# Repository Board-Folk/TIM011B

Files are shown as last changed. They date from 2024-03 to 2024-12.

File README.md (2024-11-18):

# TIM-011B

An updated remake of the TIM-011 computer from Serbia.

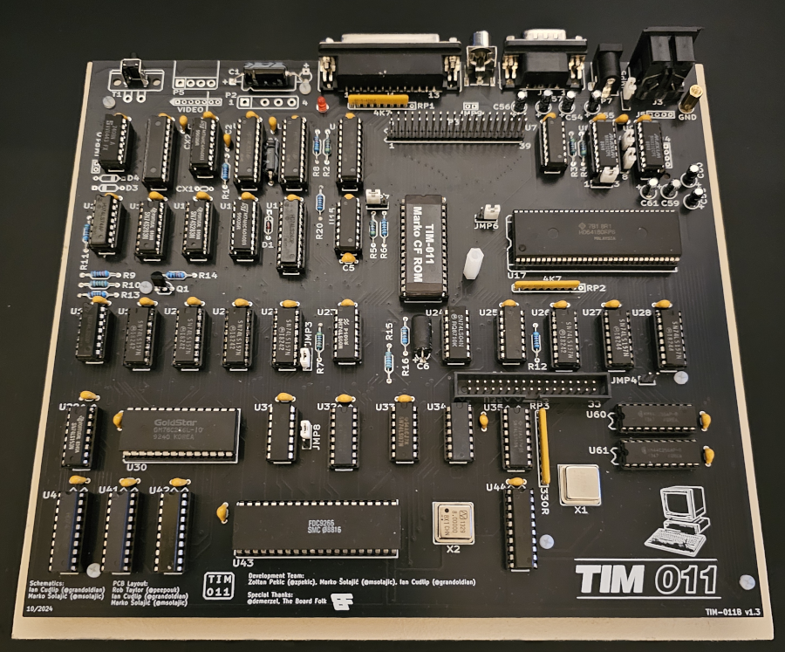
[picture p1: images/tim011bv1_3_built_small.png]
Image of build version 1.3 board in black


This repository contains the Bill-of-Materials (BOM), Gerbers and Kicad files for a remake of the TIM-011 from the Mihajlo Pupin Institute of Serbia, 1987.

The TIM-011 is a CP/M based computer that uses the Z80 family Hitachi HD64180 processor with 256KB RAM, 4 scale monochrome video and a FDC9266 floppy disk controller on the main board. It has an expansion bus, serial and parallel port and an ASCII keyboard interface. The system is built entirely from off-the-shelf parts that were commonly available at the time without any custom ULA or gate array chips. Most parts remain relatively easy to get hold of today online.

Version 1.1 does not deviate from the original board too much so it can still be considered a replica.

Version 1.2 includes 5V only operation, but due to stability issues this has not been published.

Version 1.3 contains improvements including composite video output, updated oscillators and stability fixes and uses a GAL for video sync signals. The initial version of this GAL is incompatible with the original screen, a modified version may be added in the future. From version 1.3, the board changed from using HC-49 crystals to TTL output DIP8 layout "square" can type oscillators.

Feel free to fork and make your own mods outside of this repository. Folder Extensions contains add on expansions and adapters for the board. More will follow over time.

The work-in-progress version of the board has been removed from this project. If you're looking to make one, pick the latest version from the Releases folder.

Projects are in Kicad 8.

## Building the board

A BOM is present in each release folder. The Kicad iBOM plugin has also been used to create an interactive BOM in the BOM subfolders for the main boards and expansion boards. Since these builds use obsolete parts, such as the CPU, FDC and RAM, we cannot provide any links to those parts. They are available on AliExpress and eBay, but many sellers will ship relabeled or faulty ICs. Be careful.

## Using the board

### Power

Version 1.1, as the original board requires 5V, 12V and -12V power. Power connectors on the board are the original Ei Niš connector P2, but due to the lack of availability of this part we've added P5, a standard 4 pin 3.96mm pin header to the rear of the board. 

Version 1.3 has a centre positive DC barrel jack for only 5V operation also.

### Video

Original video output is not standard, conversion is needed for use on a modern display. This works directly with the original screen and is the only output option on boards until version v1.3. The video fix extension board gives conversion to composite video for boards up to release v1.1. As a technical note, the original video output is provided as 2 TTL signals to giving 4 shades, with a relatively wide horizonal and vertical sync for the original CRT. The horizontal sync is in an awkward position and is more simlar to horizonal drive found on comparible systems with a simple in-build CRT display.

Version 1.3 adds a composite video output for use on standard monitors.

### Keyboard

The keyboard is serial ASCII, 9600 8E1 with a 12V power output on the 5 pin DIN header. Version 1.3 adds the option to switch this to 5V operation. Adapter boards are being added to the extensions folder for this and will also including modules for the v1.3 mainboard to contain keyboard conversion within the board footprint.

No operating system is included within the ROM - it needs to boot this from floppy disk or equivalent Gotek or Flash Floppy device. Marko's updated ROM for v1.3, which is backwards compatable adds diagnotics and support to boot from CF cards with the 8 bit CF/IDE expansion board and adapter.

More information to follow.

## TIM011 Resources

Marko Šolajić has put a great page together with a ROM, boot disks, software and other resources to help get the TIM-011 going. Highly recommended. The standard "sys", system ROM is 8KB, this will fit on the currently still manufactured and widely available AT28C64B.

  [TIM011 Resources](https://blog.8bitchip.info/tim011-resources/)
  
Marko is also documenting system software and has provided a new boot ROM. These can be found here:

  [TIM011 System Software](https://github.com/msolajic/tim011-system-software)

## Revisions

* Version 1.1 Initial Public Release
* Version 1.2 Unreleased
* Version 1.3 Current Release
  
### Version 1 Modifications from Original

* Fixed VSYNC Buffer
* Fix Strobe Pullup
* CX timing fix capacitor
* P5 3.96mm right angle power pin header 
* XT Keyboard INT0/SCROLL fix modification with JMP3 selection on/off
* Right angle reset momentatary switch within T1 footprint
* Modernise J3 keyboard connector footprint
* J4 and J5 serial pin headers for alternative serial connections
* Added mounting holes
* Power LED

### Version 1.1

* C42 silkscreen
* Fix J4 and J5 connections
* Silkscreen updates
* ROM A13 to GND
* Increase DB25 mounting point radius to 1.6mm
* Add JMP4 drive Ready/Disk Change modification

### Version 1.2

* 5V Only operation - added DC barrel jack
* Ceramic caps changed to 5.08mm
* Updated silkscreen
* JMP5 5V/12V keyboard selection
* A13,A14,A15 ROM options
* JMP8 No Video jumper
* Change serial to MAX232 (5V)
* RAM change to 44256
* "Half-can" Oscillators for X1 and X2
* JMP9 12V Power selection for expansion bus pin 40
* Grounding point
* Support for keyboard modules

### Version 1.3

* Replaced U2 74LS08 with GAL16V8
* Sync signals negative with standard GAL
* Change serial port to 9 pin
* Oscillators now buffered
* R8 reset pullup
* Composite video output

## Version 1.3 BOM

There are 3 options for board power, P2, P5 or P7. Ceramic capacitors 5.08mm and resistors 1/4W.

|Qty|Reference(s)|Value|Type|Notes|
|:--:|:--:|:--:|:--:|:--:|
|1|P1|5-7 pin header|Header|Video|
|1|P3|2x20 pin header|Dual Row 2.54mm Header|Expansion|
|1|P4|2x17 pin header|Dual Row 2.54mm Header|Floppy|
|1|P2|Unknown Ei Niš 4 pin header|Header|Power|
|1|P5|3.96mm 4 pin header|3.96mm Header|Alt Power|
|1|P7|DC Barrel Jack||5V Power|
|1|P8|RCA Jack||Composite Output|
|46|C3, C8, C10-C53|100nF|Ceramic Capacitor||
|1|C2|1nF|Ceramic Capacitor||
|1|C4|10uF 16V|Axial or Radial||
|1|C5|2n2|Ceramic Capacitor||
|1|C6|470uF 25V|Axial or Radial||
|8|C54-C57, C58-C61|1uF 16V|Radial||
|1|CX1, CX2|330pF|Ceramic Capacitor||
|1|D1|1N4148|Diode||
|1|D1|3mm LED|LED||
|2|R1, R12|470R|Resistor||
|1|R10|1K5|Resistor||
|1|R11|5K1|Resistor||
|2|R13, R20|1K|Resistor||
|1|R14|220R|Resistor||
|1|R15|10K|Resistor||
|1|R16|68R|Resistor||
|5|R2-R5, R7|4K7|Resistor||
|1|R6|100R|Resistor||
|1|R8|56K|Resistor||
|1|R9|2K2|Resistor||
|2|RP1, RP2|4K7 SIP10 Bussed|Resistor Network||
|1|RP3|330R SIP10 Bussed|Resistor Network||
|1|Q1|BC557|Transistor||
|1|U17|HD64180|IC|CPU|
|1|U43|FDC9266|IC|Floppy Controller|
|2|U8, U9|MAX232|IC|Serial Line Driver/Receiver|
|1|U16|27xxx ROM|IC|System ROM|
|2|U60, U61|44256 DRAM|IC|System RAM|
|1|U30|43256 SRAM|IC|Video RAM|
|1|U2|GAL16V8|IC|Sync Logic|
|1|U1|74LS08|IC||
|2|U11, U12|74LS283|IC||
|2|U14, U44|74LS240|IC||
|1|U18|74LS20|IC||
|7|U19-U22, U26-U28|74LS157|IC||
|1|U23|74LS00|IC||
|1|U24|74LS04|IC||
|1|U29|74HC153|IC||
|2|U3, U13|74HC4040|IC||
|1|U31|74LS32|IC||
|1|U32|74LS139|IC||
|1|U33|74LS07|IC||
|1|U34|74LS06|IC||
|1|U35|74LS158|IC||
|5|U4-U6, U40, U41|74LS374|IC||
|1|U42|74LS244|IC||
|4|U7, U10, U15, U25|74LS74|IC||
|1|T1|Unknown Reset Switch|Switch|T1 or T2|
|1|T2|RA Momentary Switch|Switch||
|1|J1|DB25 Female Right Angle|Socket|Printer|
|1|J3|5 pin DIN|Socket|180 degree / ASCII Keyboard|
|2|J4, J5|4 pin header|2.54mm Header|Alt TTL Serial|
|1|J6|DB9 Male Right Angle|Socket|Serial|
|1|JMP1, JMP3, JMP5-8|3 pin header|2.54mm Header||
|1|JMP2|5 pin header|2.54mm Header||
|1|JMP4|2 pin header|2.54mm Header|Fix Ready/Disk Change|
|1|X1|12.288MHz TTL Osc Can (DIP8)|Oscillator||
|1|X2|8MHz TTL Osc Can (DIP8)|Oscillator||

## Jumper Settings

Version 1.3

|Jumper|Description|Default|
|:--:|:--:|:--:|
|JMP1|CTS0 Select|2-3|
|JMP2|CTS/DCD Select|4-5,7-8|
|JMP3|XT Keyboard Fix|1-2 D Normal, 2-3 U Fix|
|JMP4|FDC Ready|Optional|
|JMP5|Keyboard Power|1-2 D 12V, 2-3 U 5V|
|JMP6|ROM A14|1-2 L 5V, 2-3 R A14|
|JMP7|ROM A15|1-2 L 5V, 2-3 R A15|
|JMP8|Video Bypass|1-2 U Normal, 2-3 D Disable|
|JMP9|12V Expansion Pin 40|NF|
|JMP10|HSYNC connection for CSYNC|Preset ON|

## Links

   [Marko's Blog Post on the TIM 011](https://blog.8bitchip.info/482-tim-011-a-new-life-for-an-old-computer/)

## Credits

PCB Layout by Rob Taylor @peepouk, Ian Cudlip @grandoldian and Marko Šolajić @msolajic. Schematics recreated and modifications by Ian Cudlip and Marko Šolajić. Special thanks to @demerzel, your schematics have helped and saved time.

## Thanks

* Zoltan Pekic
* @demerzel
* The Board Folk Team

## Legal

As the product of this project is a replica of a proprietary product, the the author makes no claim of copyright to the schematics nor PCB layouts and releases these into the public domain, solely for the purposes of study and historical preservation.

You are free to produce PCBs based on this project's designs at your own risk and without limitation, for your own use or for sale and/or repair at a reasonable price. Attribution is appreciated. The authors are not obliged to provide support of any kind. 

Under no circumstances will the authors be held responsible or liable in any way for losses, damages or costs resulting from the use of the information and/or resources of this project. 

The resources are provided "as-is" without warranty of any kind, either expressed or implied, including, but not limited to, the implied warranties of merchantability and fitness for a particular purpose.

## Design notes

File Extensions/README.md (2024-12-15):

# TIM-011B Extensions

Extension Boards for the TIM-011B

## TIMPS2Key

ATMega/Arduino based PS/2 Keyboard Adapter.

## TIMAYSound

AY-3-8910/12 expansion board for joystick and sound.

## tim011_video_fix

Video output board to create RGB and composite output from standard TIM-011 video signaling.

## TIMPS2KeyMini

Keyboard daughter card for mainboard v1.2 or later. For fitting a PS/2 keyboard interface within the mainboard footprint.

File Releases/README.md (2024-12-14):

# TIM-011B Releases

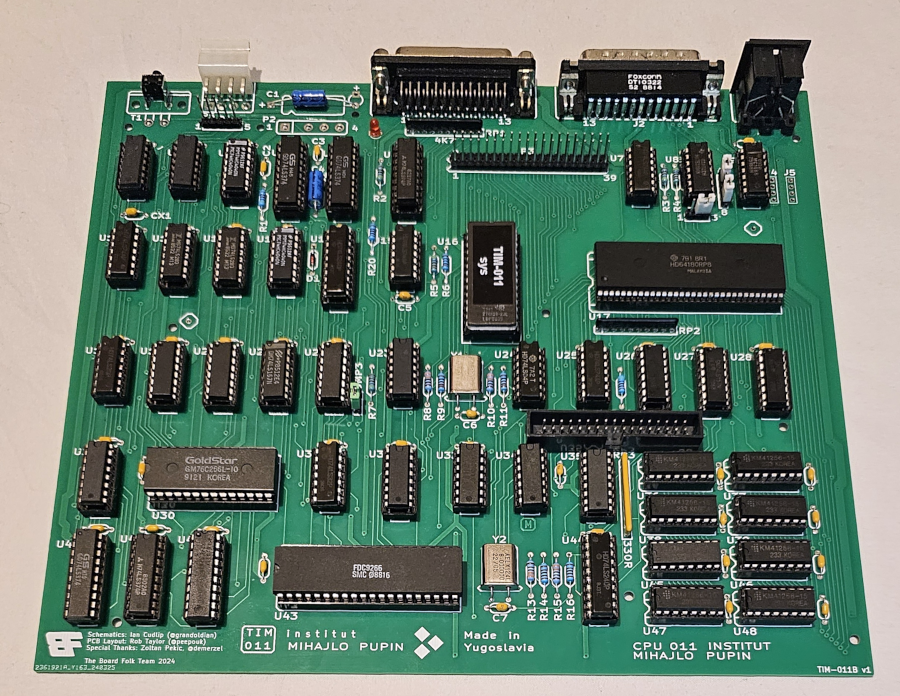
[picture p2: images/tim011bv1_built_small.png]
Image of build version 1 board in green


Each releases folder contains a Kicad, Gerbers and BOM folder, the latter containing the generated iBOM to help build the board.

Please check out the revision notes, currently on the repository home readme for changes and modifications.

## v1.1

12/04/2024

Initial public release. This doesn't deviate much from the original 1987 board.

## v1.3

16/11/2024

Contains improvements including composite video output, updated oscillators and stability fixes.

## v1.3.1

19/11/2024

Silkscreen fixes only.

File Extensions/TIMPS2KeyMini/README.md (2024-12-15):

# TIMPS2KeyMini

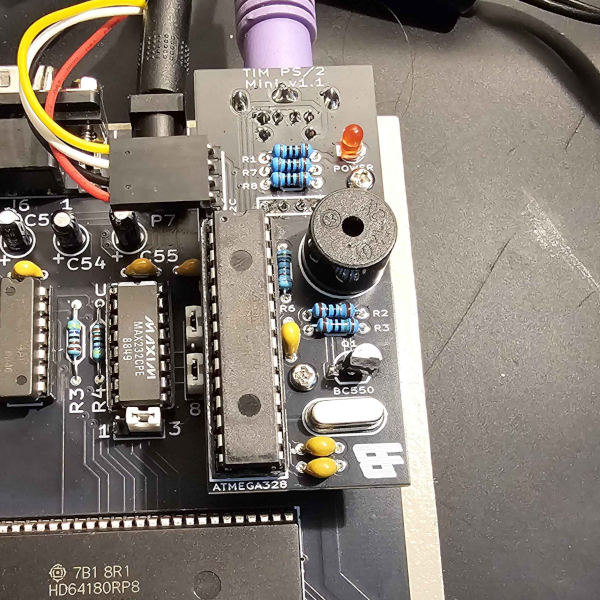
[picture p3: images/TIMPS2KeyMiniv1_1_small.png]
Image of build version 1.1 board in black


ATMega328 based PS/2 Keyboard Adapter. A daugherboard that will fit within the mainboard footprint instead of the traditional 5 pin DIN ASCII keyboard socket. This includes the i2c connector for the TIMI2CLEDPanel board which provides the LEDs.

## Versions

v1.1 Initial release

## Main board modifications

This fits instead of the external RS232 functionality of the original keyboard and connector (serial port RS232 remains). On the mainboard, do not fit the MAX232 at J9, the 5 pin DIN socket J3 and the charge caps C58-C61, fitting the 4 pin header J5 instead. Standoffs will needed to be mounted to secure the mini keyboard board and the pin length of the J5 header should match the standoff length. Recommendations may follow.

## Programming the ATMega328

The board doesn't include a programming header, the ATMega328 chip needs programming separately. The simplest way of doing this is with a Minipro with the appopriate fuse settings set in Xgpro. Tested settings are in the screenshot below and the exported binary and hex files for programming can be found in the export folder. For the arduino code see the main TIMPS2Key extension folder. 

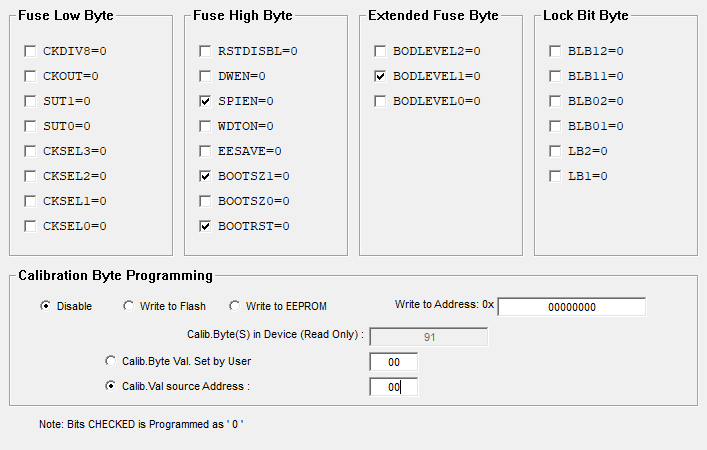
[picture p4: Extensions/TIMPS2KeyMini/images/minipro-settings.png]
Screenshot of minipro settings for the ATMega328 fuses


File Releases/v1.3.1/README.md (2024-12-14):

# TIM-011B v1.3.1

19/11/2024

Silkscreen update only, see v1.3

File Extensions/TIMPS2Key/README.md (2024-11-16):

# TIMPS2Key

ATMega/Arduino based PS/2 Keyboard Adapter. Will soon be adding the daughter board for v1.2 or later main boards which will allow fitting within the original board footprint instead of the related serial circuitry and DIN socket.

## Versions

v0 Prototype / Development board using Arduino Nano and a MAX232.

v1 Final Arduino Nano Version. Now includes sound and i2c output for LED panel.

v2 ATMEGA328 Version of v1

## Notes

For use on v1.2 or later main boards with 5V power output selected, bypass voltage regulator at U3 connecting pins 1 and 3

## TIMI2CLEDPanel

This folder contains an I2C connected board to output the keyboard LED display. It's intended to fit within a 3.5" drive blanking front panel blanking plate.

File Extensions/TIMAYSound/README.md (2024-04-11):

# TIMAYSound

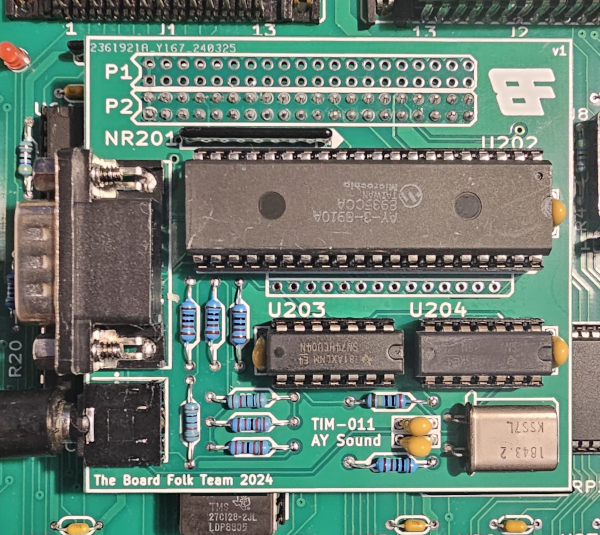
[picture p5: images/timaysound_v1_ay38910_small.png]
Image of build version 1 board in green


Sound card for the TIM-011 supporting the AY-3-8910 or AY-3-8912 sound generator chip. Featuring 3.5mm stereo line output and a DB-9 pin joystick port.

Note: Fit resistor network NR201 if you have an 'A' type chip, e.g. AY-3-8910A.

## Versions

v1 Initial version

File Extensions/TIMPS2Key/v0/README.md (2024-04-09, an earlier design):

# TIMPS2Key v0

ATMega/Arduino based PS/2 Keyboard Adapter. Prototype / Development board using Arduino Nano and a MAX232.

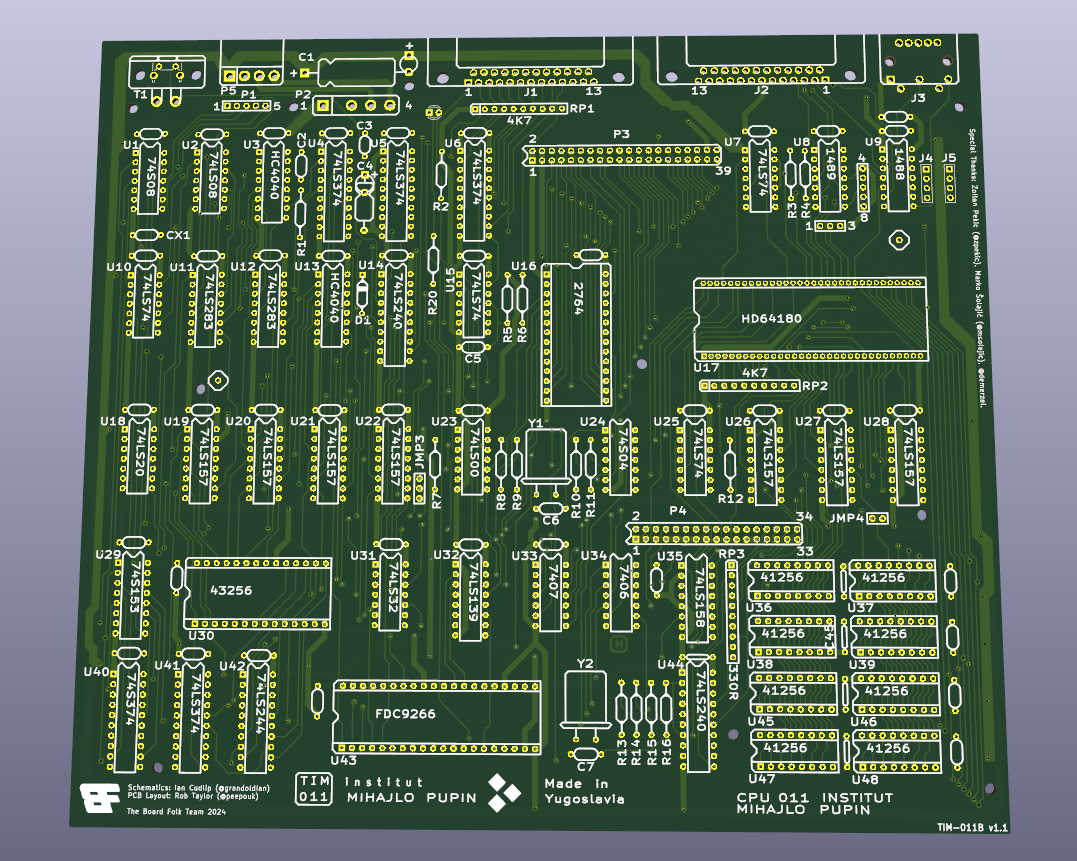
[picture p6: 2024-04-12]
images/TIM-011Bv1.1_render.png

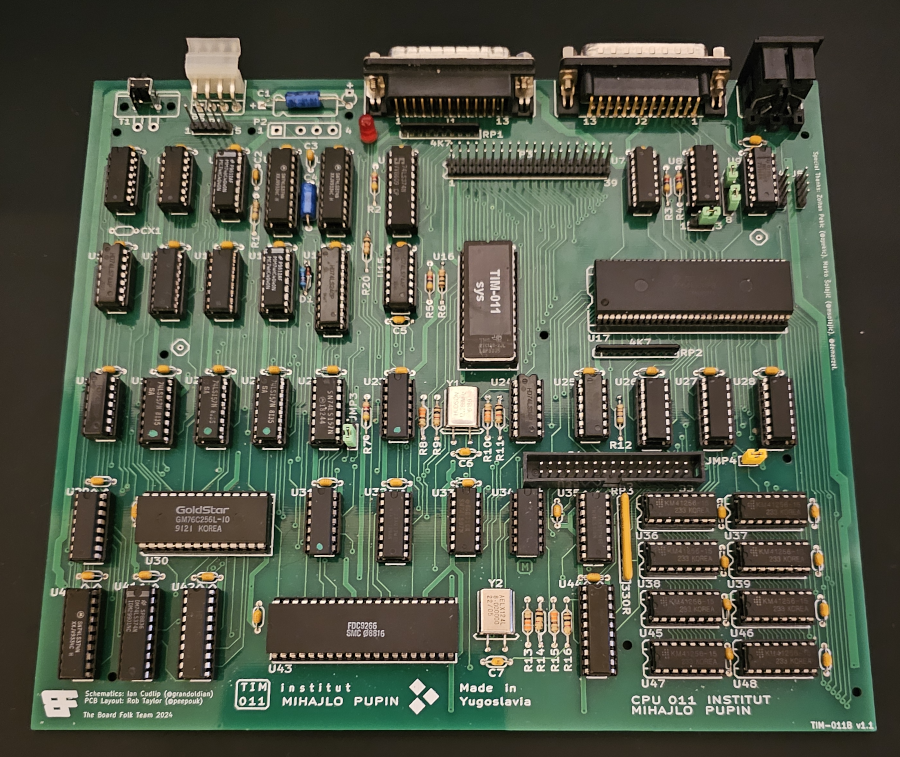
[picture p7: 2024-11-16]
images/tim011bv1_1_built_small.png

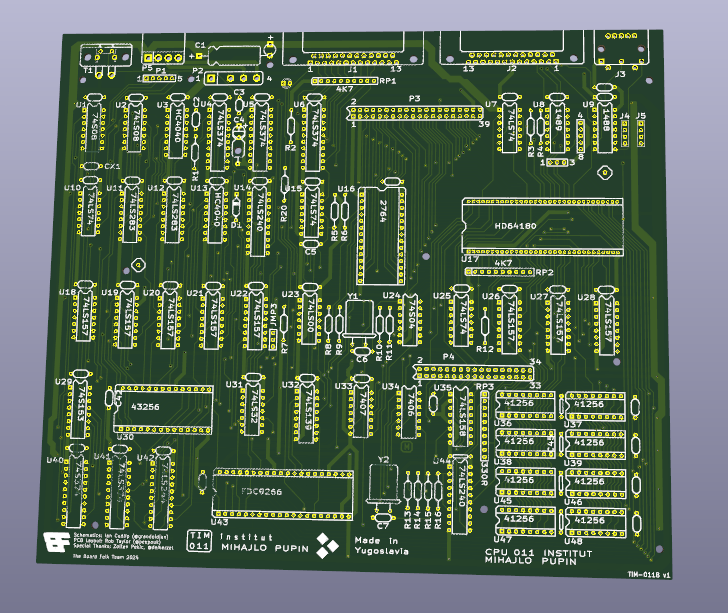
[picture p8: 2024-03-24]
images/TIM-011Bv1_render.png

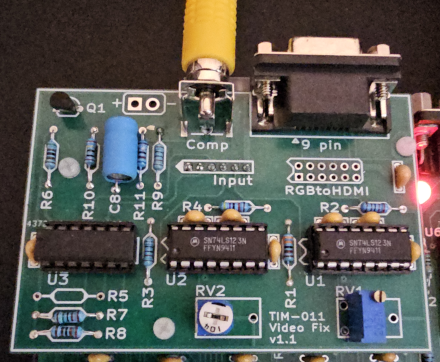
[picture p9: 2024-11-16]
images/timvideofixv1_1_small.png

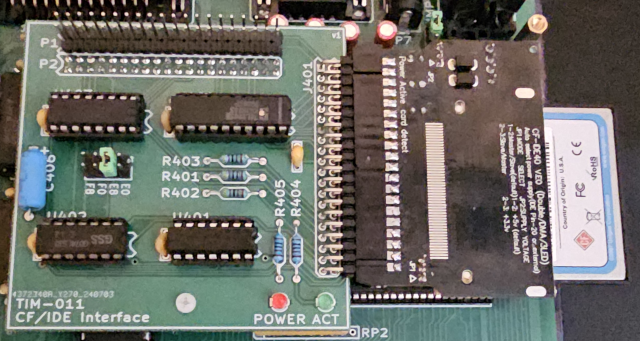
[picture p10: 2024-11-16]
images/timidev1_small.png

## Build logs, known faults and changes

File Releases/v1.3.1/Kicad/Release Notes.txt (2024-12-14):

v1 Initial Release

v1.1 

Remove C42 label
Fix J4, J5 connections
Fixed Zoltan credits silkscreen. Moved C6 and C7 down a little to avoid interference with crystals.
Fixed the 2 x silkscreen octagons so they are symmetrical.
Moved U15 designator to stop clash with R20 component and nearby via.
U18 label correction 74LS20
ROM A13 to GND
Increase DB25 mounting point radius to 1.6mm
Remove hole under C4
Credits change
Add JMP4 Floppy Ready/Disk Change Modification

v1.2

Change ceramic caps to 5.08mm
Remove IMP Branding, update credits
Change U24 label to 74LS04
JMP5 5V/12V Keyboard Voltage Selection
Connect A13 to ROM
A14,A15 ROM Jumpers JMP6, JMP7
JMP8 No Video jumper
Change 1488/1489 to MAX232
5V DC Barrel Jack
Change serial port to 9 pin
Move J5 to position as keyboard expansion
Replace RAM with 44256
"Half-can" Oscillators X1 and X2
12V Power to expansion pin 40 with JMP9
VSYNC selection jumper JMP10
TIM-011 Logo and Graphic
Grounding point

v1.3 (Attempt 1 - removed/reverted - ignore)

Remove U2 74LS08, add U2 74LS20
Move around signals to different inverter gates, free up inverters on U14 - move to U24
Update logic for generating sync signals, center image on screen with correct sync pulse length
Use (now free) inverters on U14 for creating logic for sync
Sync signals are now negative!
Rotated oscillators so they are oriented the same way with pin 1 bottom left
JMP10 is now obsolete, revert as per v1.1
Gave up on this
Reverted

v1.3

Remove U2 74LS08, add U2 GAL16V8
GAL16V8 will generate HSYNC, VSYNC, HRESET and VRESET
Sync signals are now negative!
JMP10 is now obsolete, revert as per v1.1
Serial port now changed to DE9 to make room for RCA/Composite jack
X1 moved
X1 and X2 now buffered with U44
Add R8 pull up for Reset
Added composite schematic from videofix board with adjustments and csync with diodes
JMP10 now preconfigued connection to HSYNC severable as VSYNC backfeeds back to the buffer output and original header
R13 considered optional in case of no sync on composite (remove if necessary)

v1.3.1

Update ROM Footprint

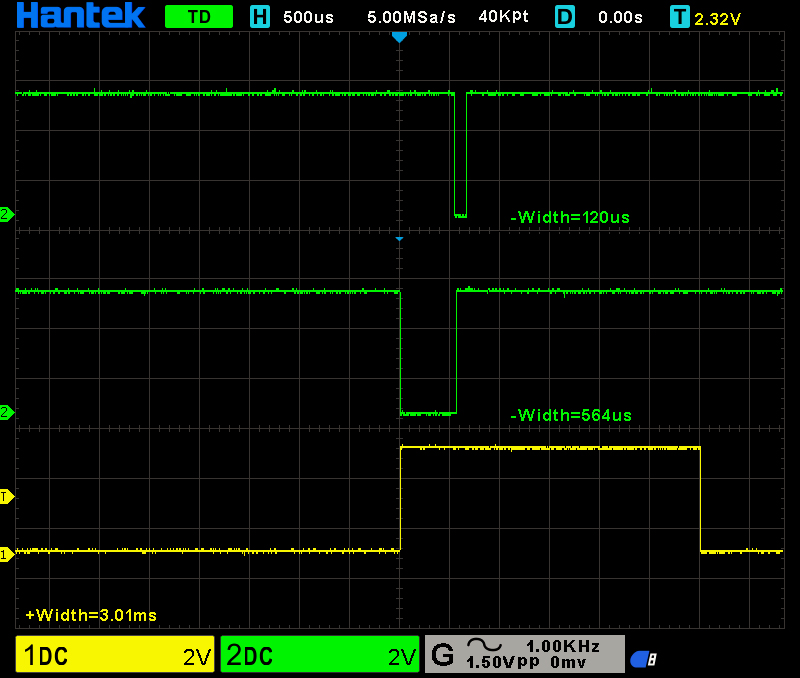
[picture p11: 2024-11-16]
Extensions/tim011_video_fix/images/vsync.jpg

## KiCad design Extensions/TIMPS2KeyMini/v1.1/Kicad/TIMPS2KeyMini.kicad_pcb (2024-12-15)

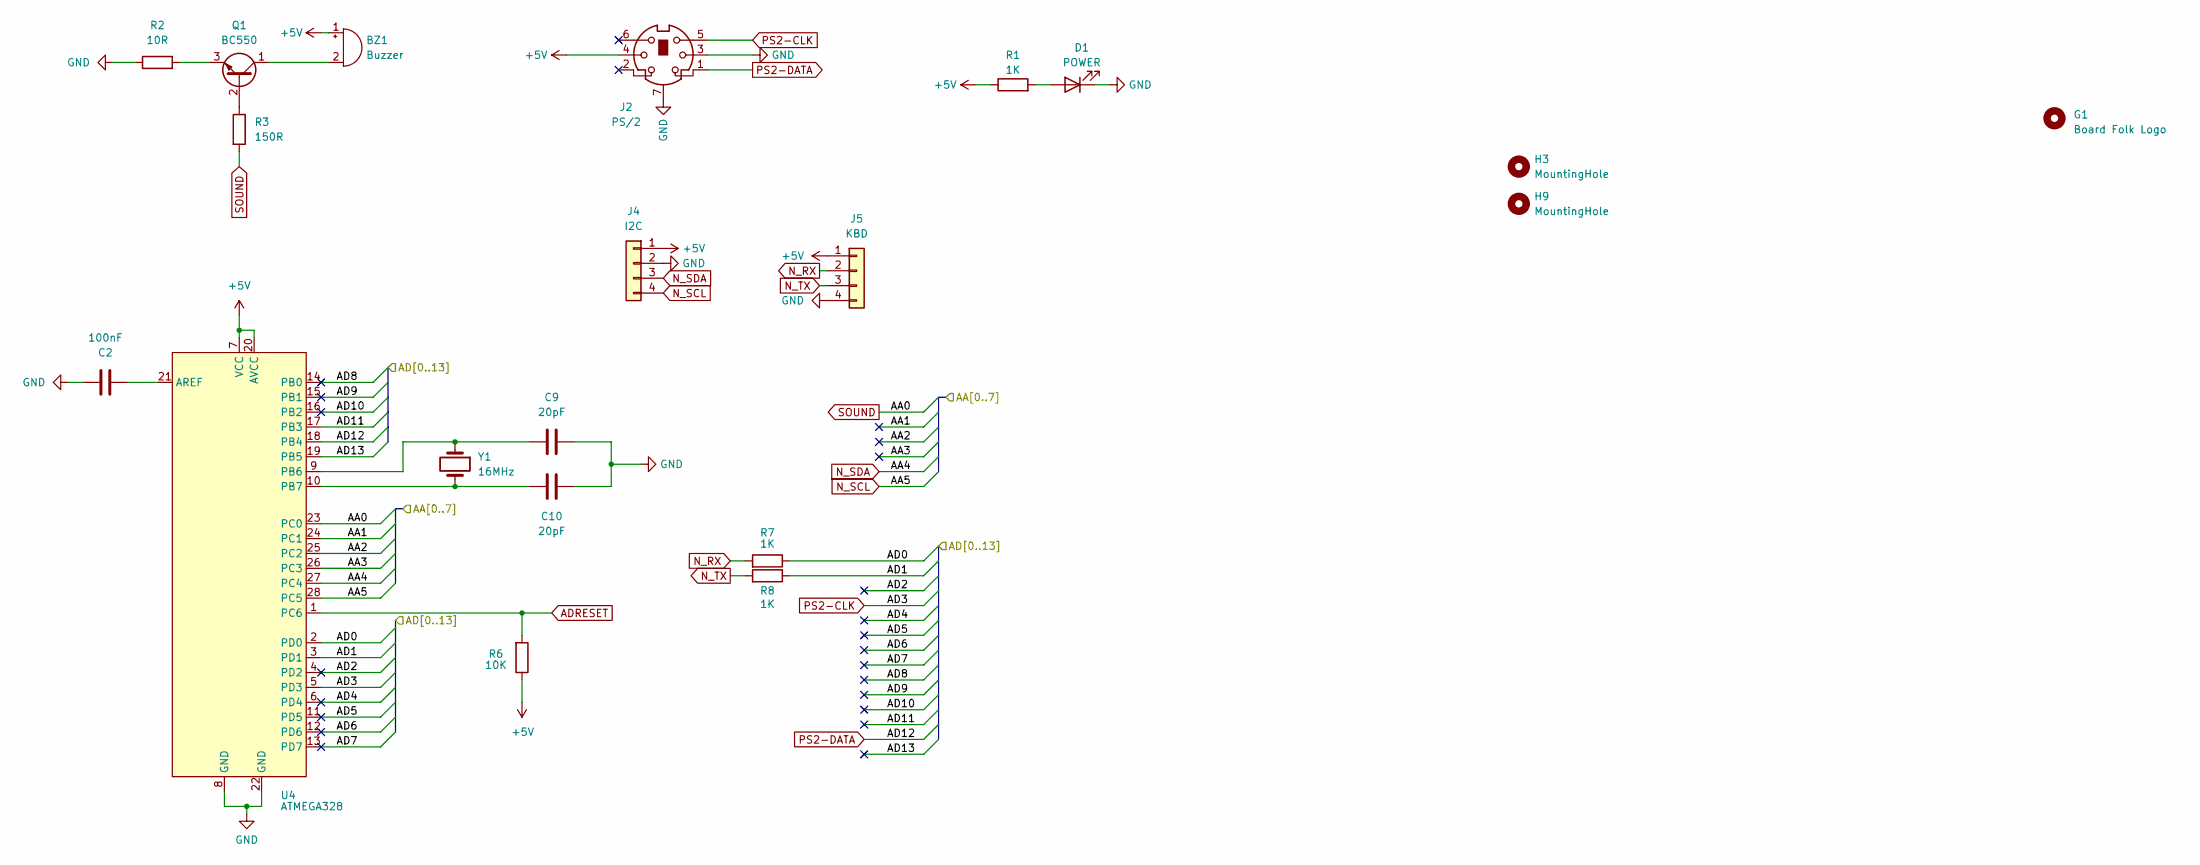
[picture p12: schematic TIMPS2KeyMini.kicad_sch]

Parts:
BZ1: Buzzer
C2: 100nF; Ceramic Cap 5.08mm
C9, C10: 20pF; Ceramic Cap 5.08mm
D1: POWER; LED_D3.0mm
G1: Board Folk Logo; BF8
H3, H9: MountingHole; MountingHole_M2.5
J2: PS/2; Connector_Mini-DIN_Female_6Pin_2rows
J4: I2C; PinHeader_1x04_2.54mm
J5: KBD; PinHeader_1x04_2.54mm
Q1: BC550; TO-92_Inline_Wide
R1, R7, R8: 1K; Resistor 7.62mm
R2: 10R; Resistor 7.62mm
R3: 150R; Resistor 7.62mm
R6: 10K; Resistor 7.62mm
U4: ATMEGA328; DIP-28_W7.62mm_Socket
Y1: 16MHz; Crystal_HC49-U_Vertical

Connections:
+5V: BZ1.1 (+), J2.4, J4.1, J5.1, R1.1, R6.1, U4.7 (VCC), U4.20 (AVCC)
/AA1: U4.24 (PC1)
/AA2: U4.25 (PC2)
/AA3: U4.26 (PC3)
/AD0: R7.1, U4.2 (PD0)
/AD1: R8.1, U4.3 (PD1)
/AD2: U4.4 (PD2)
/AD4: U4.6 (PD4)
/AD5: U4.11 (PD5)
/AD6: U4.12 (PD6)
/AD7: U4.13 (PD7)
/AD8: U4.14 (PB0)
/AD9: U4.15 (PB1)
/AD10: U4.16 (PB2)
/AD11: U4.17 (PB3)
/AD13: U4.19 (PB5)
ADRESET: R6.2, U4.1 (PC6)
GND: C2.2, C9.2, C10.2, D1.1 (K), J2.3, J2.7, J4.2, J5.4, R2.1, U4.8 (GND), U4.22 (GND)
N_RX: J5.2, R7.2
N_SCL: J4.4, U4.28 (PC5)
N_SDA: J4.3, U4.27 (PC4)
N_TX: J5.3, R8.2
unnamed: BZ1.2 (-), Q1.1 (C)
unnamed: D1.2 (A), R1.2
unnamed: Q1.2 (B), R3.1
unnamed: Q1.3 (E), R2.2
unnamed: C2.1, U4.21 (AREF)
unnamed: C9.1, U4.9 (PB6), Y1.1
unnamed: C10.1, U4.10 (PB7), Y1.2
PS2-CLK: J2.5, U4.5 (PD3)
PS2-DATA: J2.1, U4.18 (PB4)
SOUND: R3.2, U4.23 (PC0)

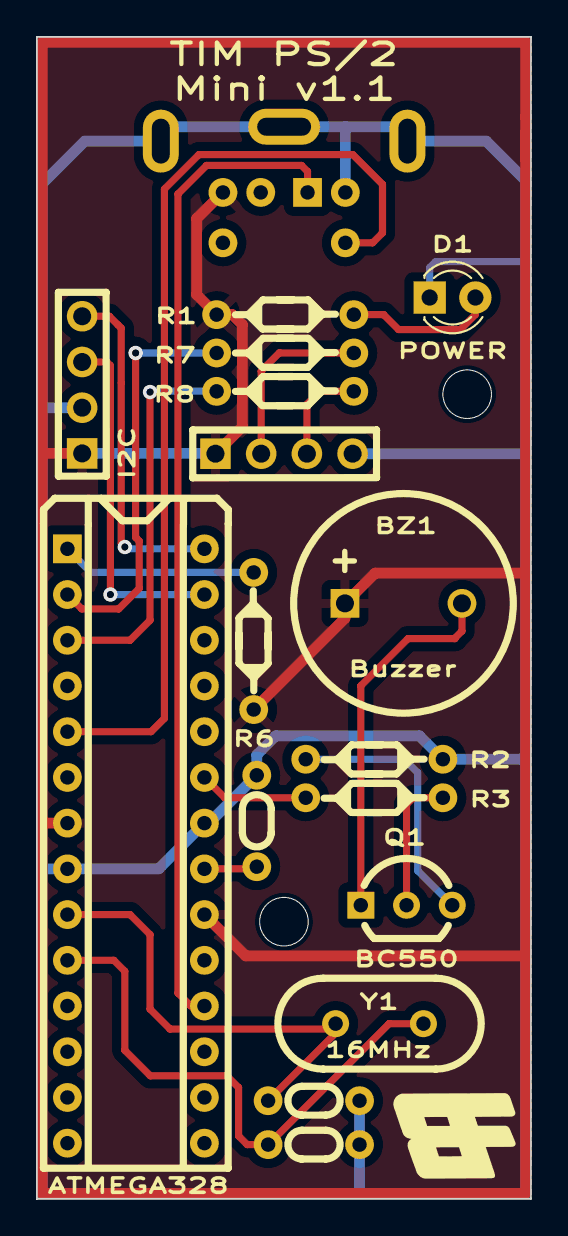
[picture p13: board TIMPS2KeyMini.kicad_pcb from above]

Board: 2 copper layers, 27.5 x 64.6 mm, 20 parts (1 on the bottom side), 19 nets.

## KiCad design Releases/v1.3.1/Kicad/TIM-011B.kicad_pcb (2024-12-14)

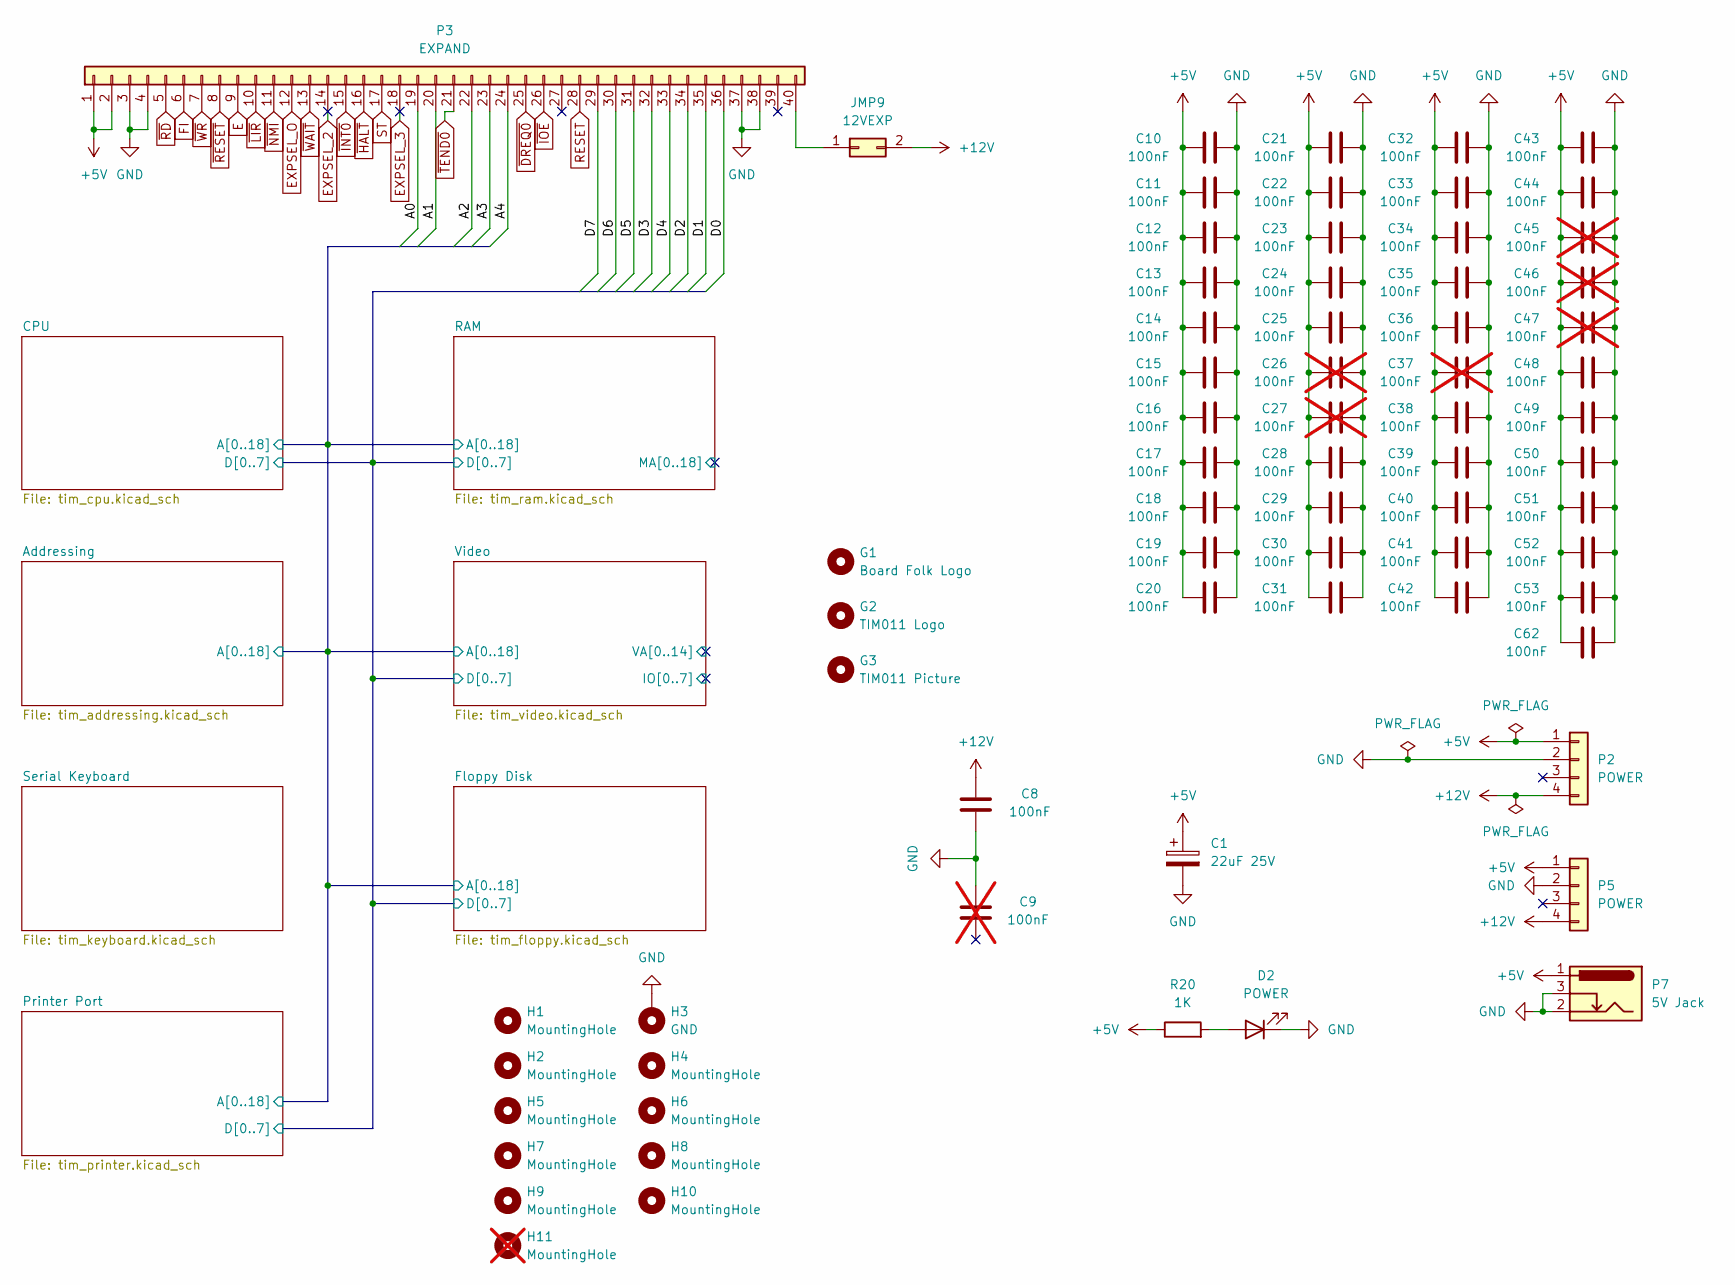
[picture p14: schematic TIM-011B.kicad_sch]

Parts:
C1: 22uF 25V; Electrolytic Capacitor Axial or Radial
C8, C10, C11, C12, C13, C14, C15, C16, C17, C18, C19, C20, C21, C22, C23, C24, C25, C28, C29, C30, C31, C32, C33, C34, C35, C36, C38, C39, C40, C41, C42, C43, C44, C48, C49, C50, C51, C52, C53, C62: 100nF; Ceramic Cap 5.08mm
C9, C26, C27, C37, C45, C46, C47: 100nF; Ceramic Cap 5.08mm; not fitted
D2: POWER; LED_D3.0mm
G1: Board Folk Logo; BF8
G2: TIM011 Logo; tim011logo
G3: TIM011 Picture; tim011_picture
H1, H2, H4, H5, H6, H7, H8, H9, H10: MountingHole; MountingHole_M2.5
H3: GND; TIM_MountingHole_2.5mm_Pad
H11: MountingHole; MountingHole_M2.5; not fitted
JMP9: 12VEXP; PinHeader_1x02 2.54mm
P2: POWER; P2
P3: EXPAND; PinHeader_2x20 2.54mm
P5: POWER; 3.96mm Header 4-Pin Edge
P7: 5V Jack; TIM_BarrelJack_Horizontal
R20: 1K; Resistor 12.7mm

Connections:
+5V: C1.1, C10.1, C11.1, C12.1, C13.1, C14.1, C15.1, C16.1, C17.1, C18.1, C19.1, C20.1, C21.1, C22.1, C23.1, C24.1, C25.1, C26.1, C27.1, C28.1, C29.1, C30.1, C31.1, C32.1, C33.1, C34.1, C35.1, C36.1, C37.1, C38.1, C39.1, C40.1, C41.1, C42.1, C43.1, C44.1, C45.1, C46.1, C47.1, C48.1, C49.1, C50.1, C51.1, C52.1, C53.1, C62.1, P2.1, P3.1, P3.2, P5.1, P7.1, R20.1; also elsewhere on the board
+12V: C8.1, JMP9.2, P2.4, P5.4; also elsewhere on the board
/Addressing/A0: P3.19; also elsewhere on the board
/Addressing/A1: P3.20; also elsewhere on the board
/Addressing/A2: P3.22; also elsewhere on the board
/Addressing/A3: P3.23; also elsewhere on the board
/Addressing/A4: P3.24; also elsewhere on the board
/CPU/D0: P3.36; also elsewhere on the board
/CPU/D1: P3.35; also elsewhere on the board
/CPU/D2: P3.34; also elsewhere on the board
/CPU/D3: P3.32; also elsewhere on the board
/CPU/D4: P3.33; also elsewhere on the board
/CPU/D5: P3.31; also elsewhere on the board
/CPU/D6: P3.30; also elsewhere on the board
/CPU/D7: P3.29; also elsewhere on the board
E: P3.9; also elsewhere on the board
EXPSEL_2: P3.14
EXPSEL_3: P3.18
EXPSEL_O: P3.12; also elsewhere on the board
FI: P3.6; also elsewhere on the board
GND: C1.2, C8.2, C9.1, C10.2, C11.2, C12.2, C13.2, C14.2, C15.2, C16.2, C17.2, C18.2, C19.2, C20.2, C21.2, C22.2, C23.2, C24.2, C25.2, C26.2, C27.2, C28.2, C29.2, C30.2, C31.2, C32.2, C33.2, C34.2, C35.2, C36.2, C37.2, C38.2, C39.2, C40.2, C41.2, C42.2, C43.2, C44.2, C45.2, C46.2, C47.2, C48.2, C49.2, C50.2, C51.2, C52.2, C53.2, C62.2, D2.1 (K), H3.1, P2.2, P3.3, P3.4, P3.37, P3.38, P5.2, P7.2, P7.3; also elsewhere on the board
unnamed: D2.2 (A), R20.2
unnamed: JMP9.1, P3.40
RESET: P3.28; also elsewhere on the board
ST: P3.17; also elsewhere on the board
~DREQ0: P3.25; also elsewhere on the board
~HALT: P3.16; also elsewhere on the board
~INT0: P3.15; also elsewhere on the board
~IOE: P3.26; also elsewhere on the board
~LIR: P3.10; also elsewhere on the board
~NMI: P3.11; also elsewhere on the board
~RD: P3.5; also elsewhere on the board
~RESET: P3.8; also elsewhere on the board
~TEND0: P3.21; also elsewhere on the board
~WAIT: P3.13; also elsewhere on the board
~WR: P3.7; also elsewhere on the board

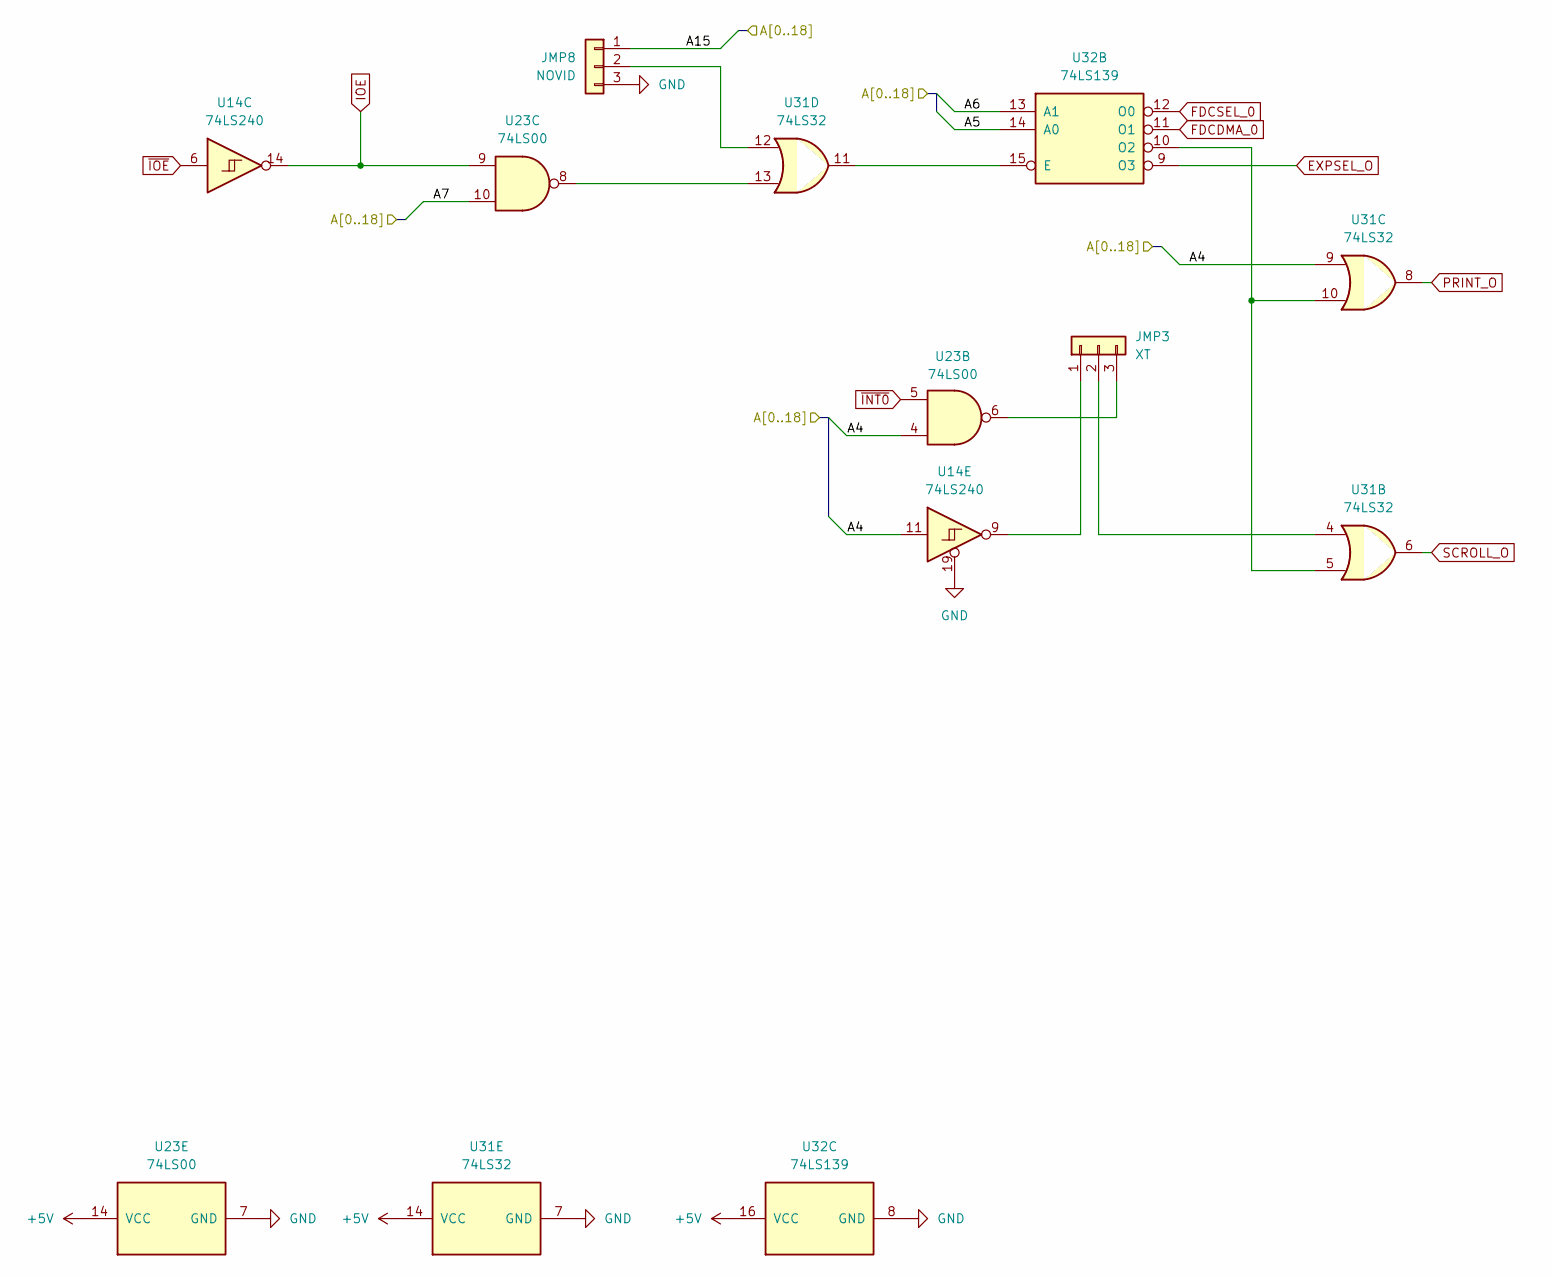
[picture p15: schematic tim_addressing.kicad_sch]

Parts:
JMP3: XT; PinHeader_1x03 2.54mm
JMP8: NOVID; PinHeader_1x03 2.54mm
U14: 74LS240; DIP-20_W7.62mm
U23: 74LS00; DIP-14_W7.62mm
U31: 74LS32; DIP-14_W7.62mm
U32: 74LS139; DIP-16_W7.62mm

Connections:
+5V: U23.14 (VCC), U31.14 (VCC), U32.16 (VCC); also elsewhere on the board
/Addressing/A4: U14.11, U23.4, U31.9; also elsewhere on the board
/Addressing/A5: U32.14 (A0); also elsewhere on the board
/Addressing/A6: U32.13 (A1); also elsewhere on the board
/Addressing/A7: U23.10; also elsewhere on the board
/Addressing/A15: JMP8.1; also elsewhere on the board
EXPSEL_O: U32.9 (O3); also elsewhere on the board
FDCDMA_0: U32.11 (O1); also elsewhere on the board
FDCSEL_0: U32.12 (O0); also elsewhere on the board
GND: JMP8.3, U14.19, U23.7 (GND), U31.7 (GND), U32.8 (GND); also elsewhere on the board
IOE: U14.14, U23.9; also elsewhere on the board
unnamed: JMP3.1, U14.9
unnamed: JMP3.2, U31.4
unnamed: JMP3.3, U23.6
unnamed: JMP8.2, U31.12
unnamed: U23.8, U31.13
unnamed: U31.11, U32.15 (E)
unnamed: U31.5, U31.10, U32.10 (O2)
PRINT_O: U31.8; also elsewhere on the board
SCROLL_O: U31.6; also elsewhere on the board
~INT0: U23.5; also elsewhere on the board
~IOE: U14.6; also elsewhere on the board

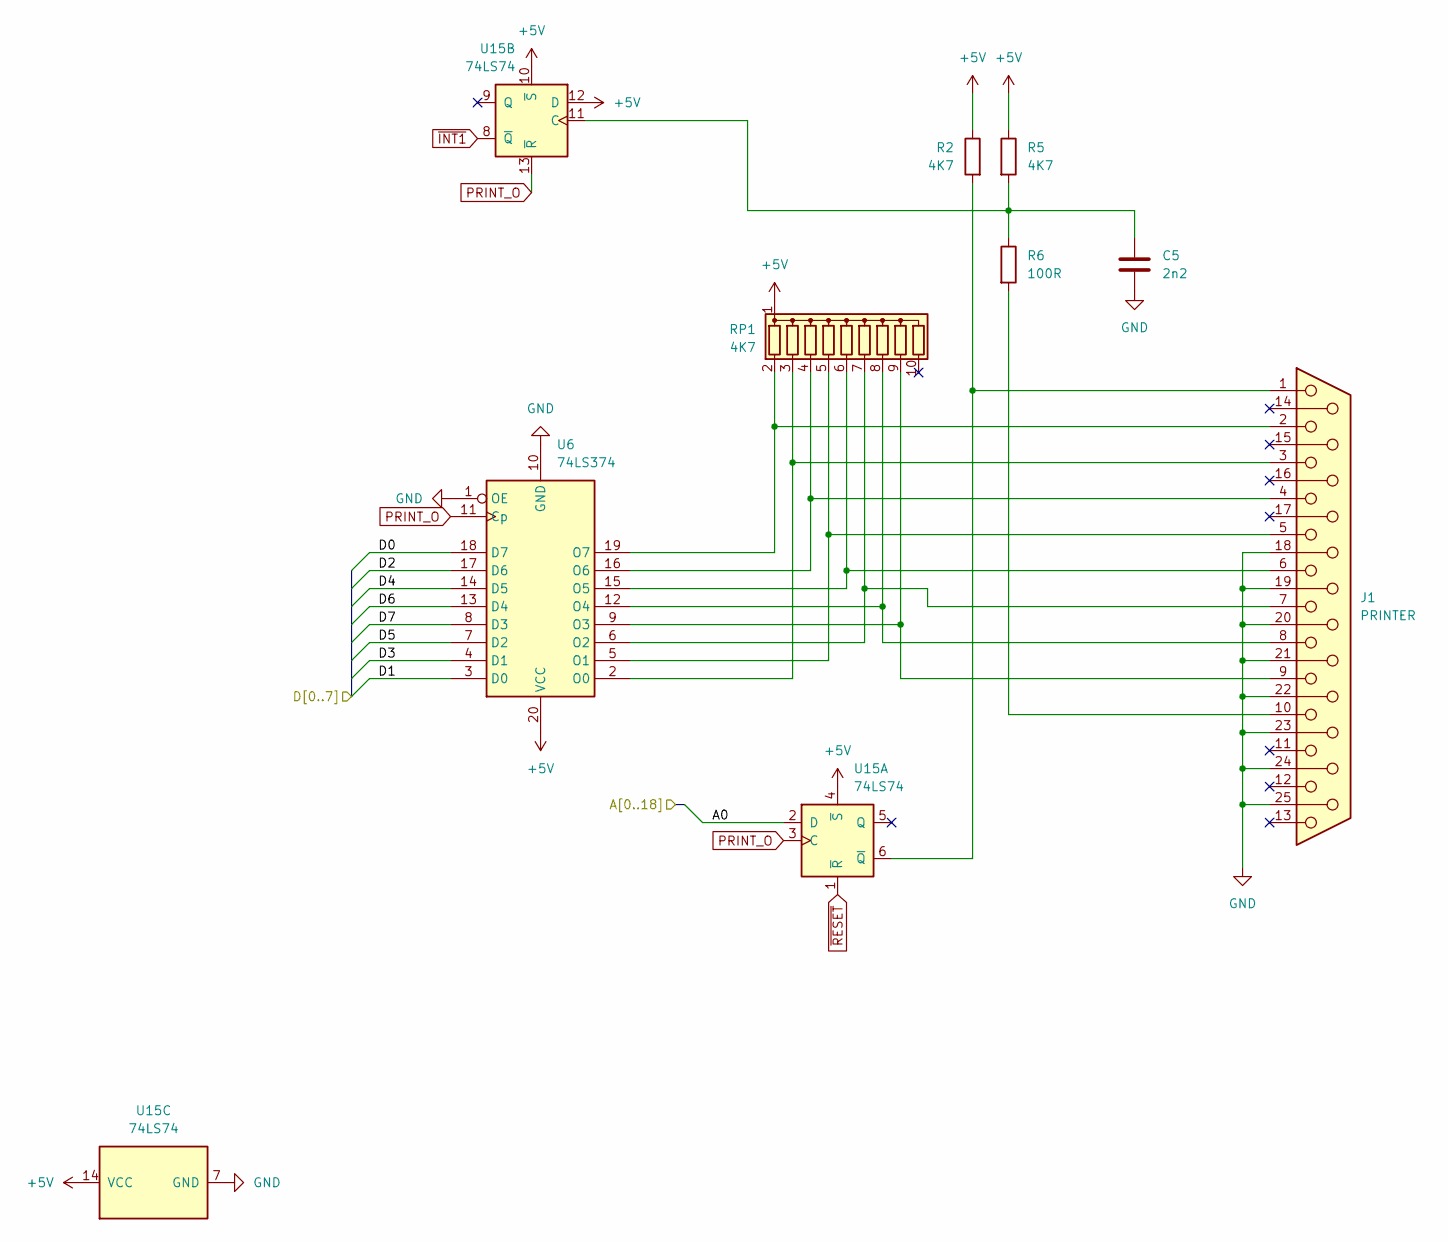
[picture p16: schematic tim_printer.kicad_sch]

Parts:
C5: 2n2; Ceramic Cap 5.08mm
J1: PRINTER
R2, R5: 4K7; Resistor 12.7mm
R6: 100R; Resistor 12.7mm
RP1: 4K7; R_Array_SIP10
U6: 74LS374; DIP-20_W7.62mm
U15: 74LS74; DIP-14_W7.62mm

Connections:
+5V: R2.1, R5.1, RP1.1 (common), U6.20 (VCC), U15.4 (~S), U15.10 (~S), U15.12 (D), U15.14 (VCC); also elsewhere on the board
/Addressing/A0: U15.2 (D); also elsewhere on the board
/CPU/D0: U6.18 (D7); also elsewhere on the board
/CPU/D1: U6.3 (D0); also elsewhere on the board
/CPU/D2: U6.17 (D6); also elsewhere on the board
/CPU/D3: U6.4 (D1); also elsewhere on the board
/CPU/D4: U6.14 (D5); also elsewhere on the board
/CPU/D5: U6.7 (D2); also elsewhere on the board
/CPU/D6: U6.13 (D4); also elsewhere on the board
/CPU/D7: U6.8 (D3); also elsewhere on the board
GND: C5.2, J1.18, J1.19, J1.20, J1.21, J1.22, J1.23, J1.24, J1.25, U6.1 (OE), U6.10 (GND), U15.7 (GND); also elsewhere on the board
unnamed: J1.10, R6.2
unnamed: J1.2, RP1.2 (R1), U6.19 (O7)
unnamed: J1.3, RP1.3 (R2), U6.2 (O0)
unnamed: J1.4, RP1.4 (R3), U6.16 (O6)
unnamed: J1.5, RP1.5 (R4), U6.5 (O1)
unnamed: J1.6, RP1.6 (R5), U6.15 (O5)
unnamed: J1.7, RP1.7 (R6), U6.6 (O2)
unnamed: J1.8, RP1.8 (R7), U6.12 (O4)
unnamed: J1.9, RP1.9 (R8), U6.9 (O3)
unnamed: J1.1, R2.2, U15.6 (~Q)
unnamed: C5.1, R5.2, R6.1, U15.11 (C)
PRINT_O: U6.11 (Cp), U15.3 (C), U15.13 (~R); also elsewhere on the board
~INT1: U15.8 (~Q); also elsewhere on the board
~RESET: U15.1 (~R); also elsewhere on the board

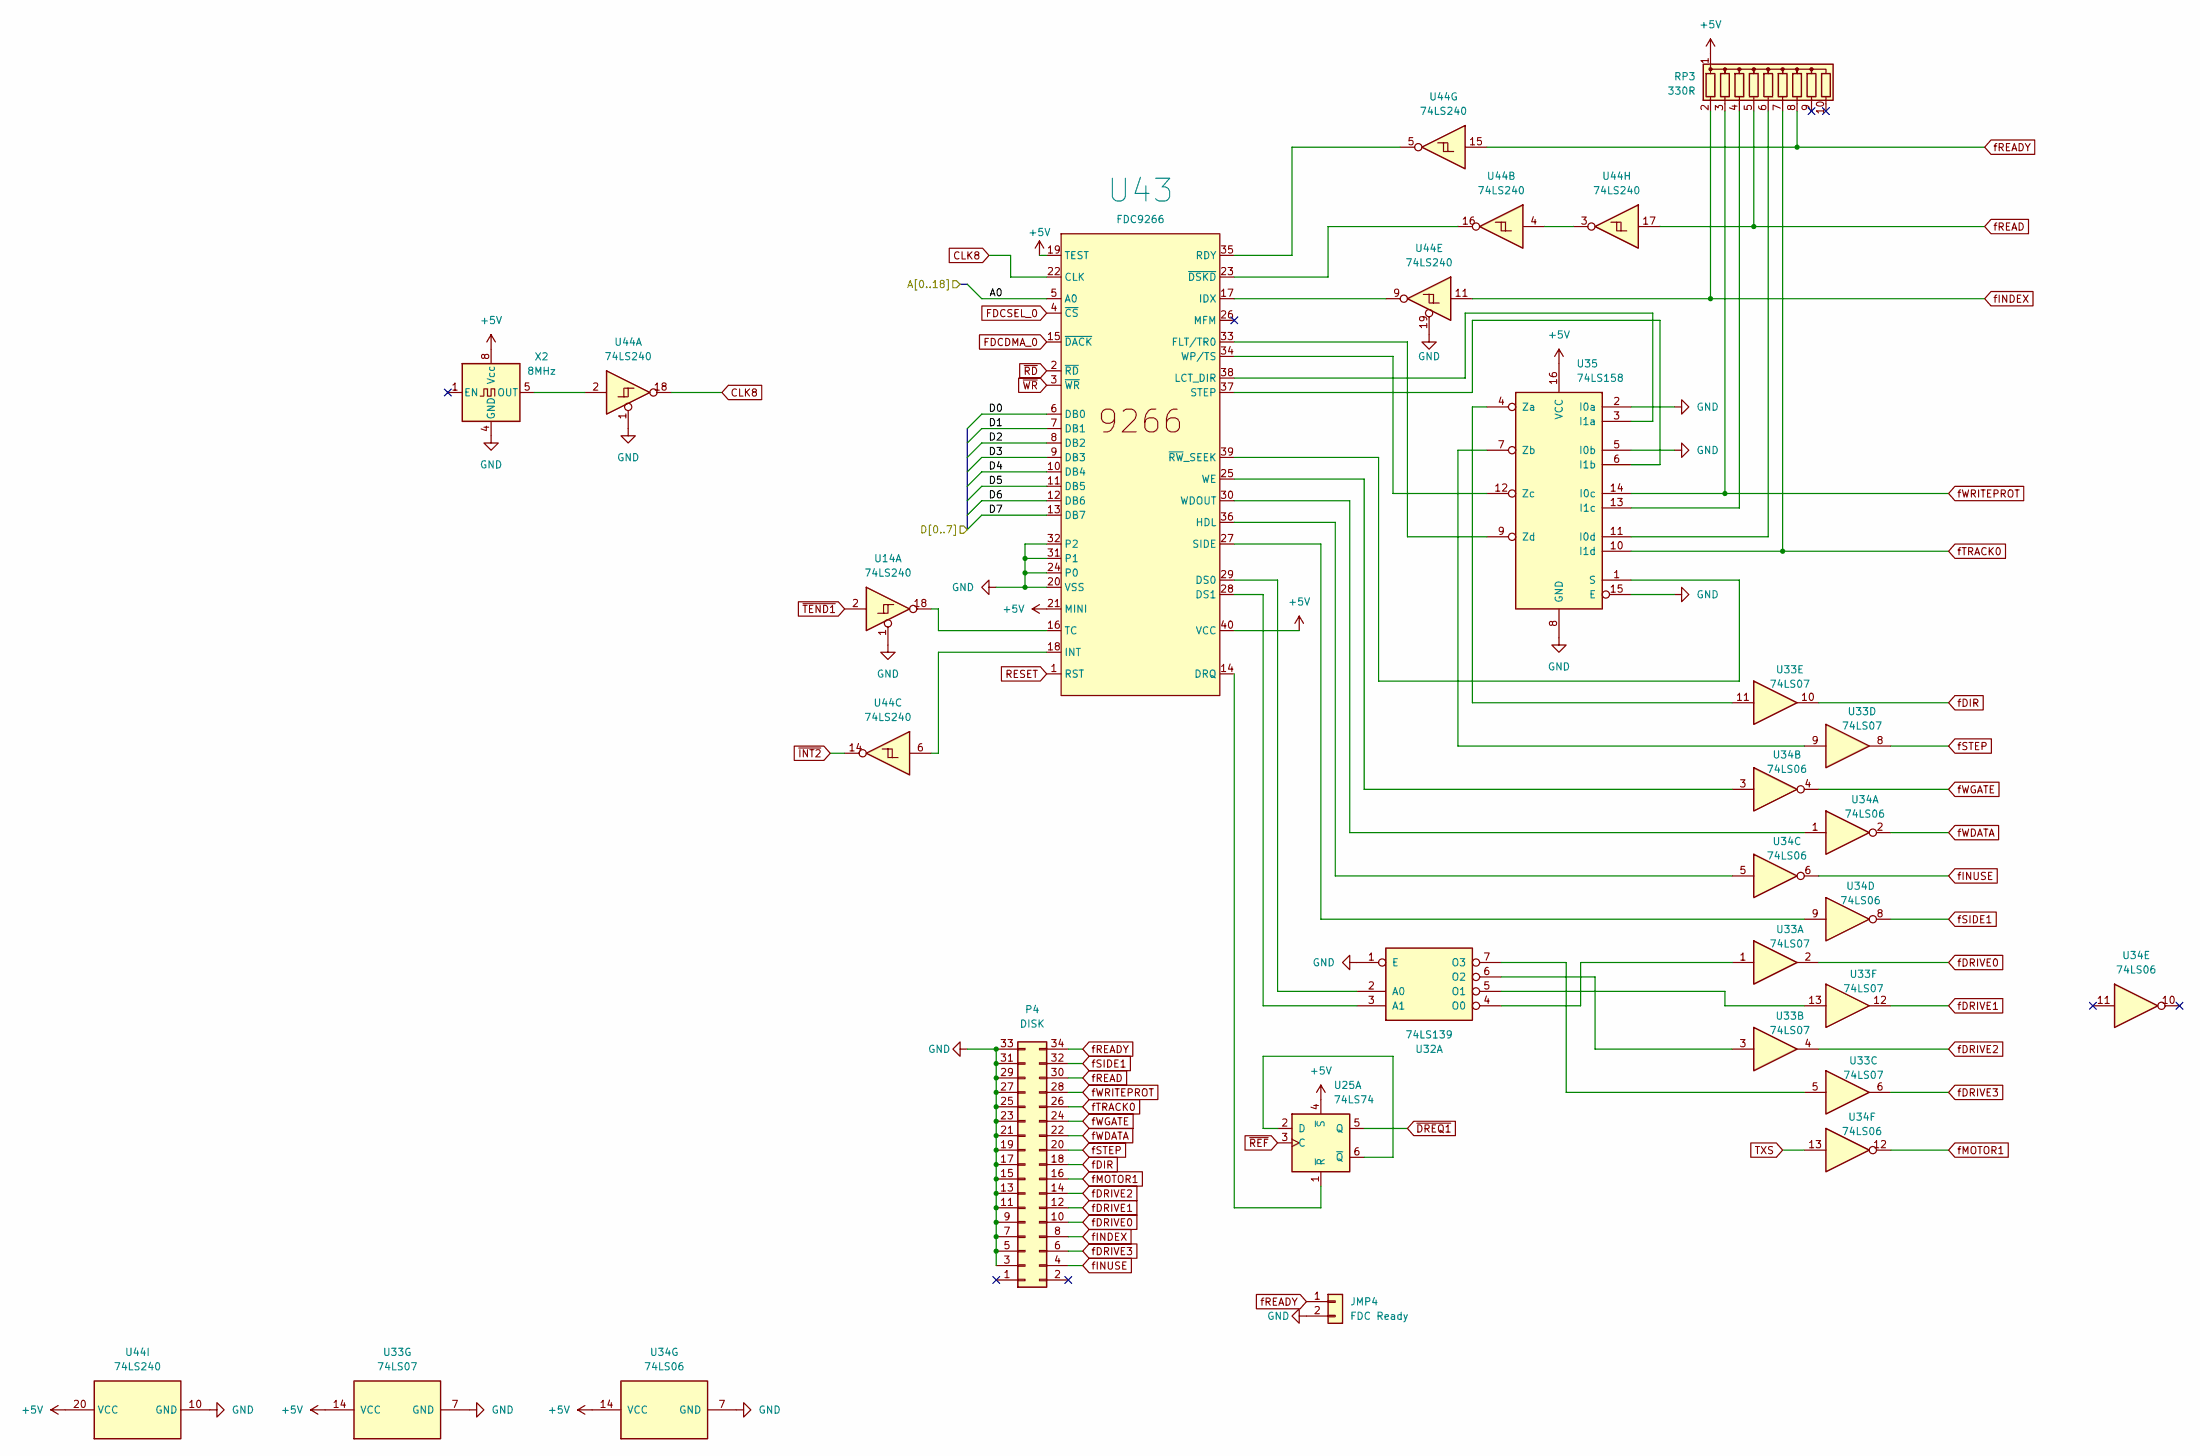
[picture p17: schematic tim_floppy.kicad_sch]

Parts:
JMP4: FDC Ready; PinHeader_1x02 2.54mm
P4: DISK; PinHeader_2x17_2.54mm
RP3: 330R; R_Array_SIP10
U14, U44: 74LS240; DIP-20_W7.62mm
U25: 74LS74; DIP-14_W7.62mm
U32: 74LS139; DIP-16_W7.62mm
U33: 74LS07; DIP-14_W7.62mm
U34: 74LS06; DIP-14_W7.62mm
U35: 74LS158; DIP-16_W7.62mm
U43: FDC9266; DIP-40_W15.24mm_Socket
X2: 8MHz; TIM_Oscillator_DIP-8

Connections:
+5V: RP3.1 (common), U25.4 (~S), U33.14 (VCC), U34.14 (VCC), U35.16 (VCC), U43.19 (TEST), U43.21 (MINI), U43.40 (VCC), U44.20 (VCC), X2.8 (Vcc); also elsewhere on the board
/Addressing/A0: U43.5 (A0); also elsewhere on the board
/CPU/D0: U43.6 (DB0); also elsewhere on the board
/CPU/D1: U43.7 (DB1); also elsewhere on the board
/CPU/D2: U43.8 (DB2); also elsewhere on the board
/CPU/D3: U43.9 (DB3); also elsewhere on the board
/CPU/D4: U43.10 (DB4); also elsewhere on the board
/CPU/D5: U43.11 (DB5); also elsewhere on the board
/CPU/D6: U43.12 (DB6); also elsewhere on the board
/CPU/D7: U43.13 (DB7); also elsewhere on the board
CLK8: U43.22 (CLK), U44.18
FDCDMA_0: U43.15 (~DACK); also elsewhere on the board
FDCSEL_0: U43.4 (~CS); also elsewhere on the board
GND: JMP4.2, P4.3, P4.5, P4.7, P4.9, P4.11, P4.13, P4.15, P4.17, P4.19, P4.21, P4.23, P4.25, P4.27, P4.29, P4.31, P4.33, U14.1, U32.1 (E), U33.7 (GND), U34.7 (GND), U35.2 (I0a), U35.5 (I0b), U35.8 (GND), U35.15 (E), U43.20 (VSS), U43.24 (P0), U43.31 (P1), U43.32 (P2), U44.1, U44.10 (GND), U44.19, X2.4 (GND); also elsewhere on the board
unnamed: RP3.4 (R3), U35.13 (I1c)
unnamed: RP3.6 (R5), U35.11 (I0d)
unnamed: U25.2 (D), U25.6 (~Q)
unnamed: U25.1 (~R), U43.14 (DRQ)
unnamed: U32.2 (A0), U43.29 (DS0)
unnamed: U32.3 (A1), U43.28 (DS1)
unnamed: U32.4 (O0), U33.1
unnamed: U32.5 (O1), U33.13
unnamed: U32.6 (O2), U33.3
unnamed: U32.7 (O3), U33.5
unnamed: U35.3 (I1a), U43.38 (LCT_DIR)
unnamed: U35.6 (I1b), U43.37 (STEP)
unnamed: U35.1 (S), U43.39 (~RW_SEEK)
unnamed: U33.11, U35.4 (Za)
unnamed: U33.9, U35.7 (Zb)
unnamed: U35.12 (Zc), U43.34 (WP/TS)
unnamed: U35.9 (Zd), U43.33 (FLT/TR0)
unnamed: U34.5, U43.36 (HDL)
unnamed: U43.17 (IDX), U44.9
unnamed: U43.18 (INT), U44.6
unnamed: U43.35 (RDY), U44.5
unnamed: U34.9, U43.27 (SIDE)
unnamed: U14.18, U43.16 (TC)
unnamed: U34.1, U43.30 (WDOUT)
unnamed: U34.3, U43.25 (WE)
unnamed: U43.23 (~DSKD), U44.16
unnamed: U44.3, U44.4
unnamed: U44.2, X2.5 (OUT)
RESET: U43.1 (RST); also elsewhere on the board
TXS: U34.13; also elsewhere on the board
fDIR: P4.18, U33.10
fDRIVE0: P4.10, U33.2
fDRIVE1: P4.12, U33.12
fDRIVE2: P4.14, U33.4
fDRIVE3: P4.6, U33.6
fINDEX: P4.8, RP3.2 (R1), U44.11
fINUSE: P4.4, U34.6
fMOTOR1: P4.16, U34.12
fREAD: P4.30, RP3.5 (R4), U44.17
fREADY: JMP4.1, P4.34, RP3.8 (R7), U44.15
fSIDE1: P4.32, U34.8
fSTEP: P4.20, U33.8
fTRACK0: P4.26, RP3.7 (R6), U35.10 (I1d)
fWDATA: P4.22, U34.2
fWGATE: P4.24, U34.4
fWRITEPROT: P4.28, RP3.3 (R2), U35.14 (I0c)
~DREQ1: U25.5 (Q); also elsewhere on the board
~INT2: U44.14; also elsewhere on the board
~RD: U43.2 (~RD); also elsewhere on the board
~REF: U25.3 (C); also elsewhere on the board
~TEND1: U14.2; also elsewhere on the board
~WR: U43.3 (~WR); also elsewhere on the board

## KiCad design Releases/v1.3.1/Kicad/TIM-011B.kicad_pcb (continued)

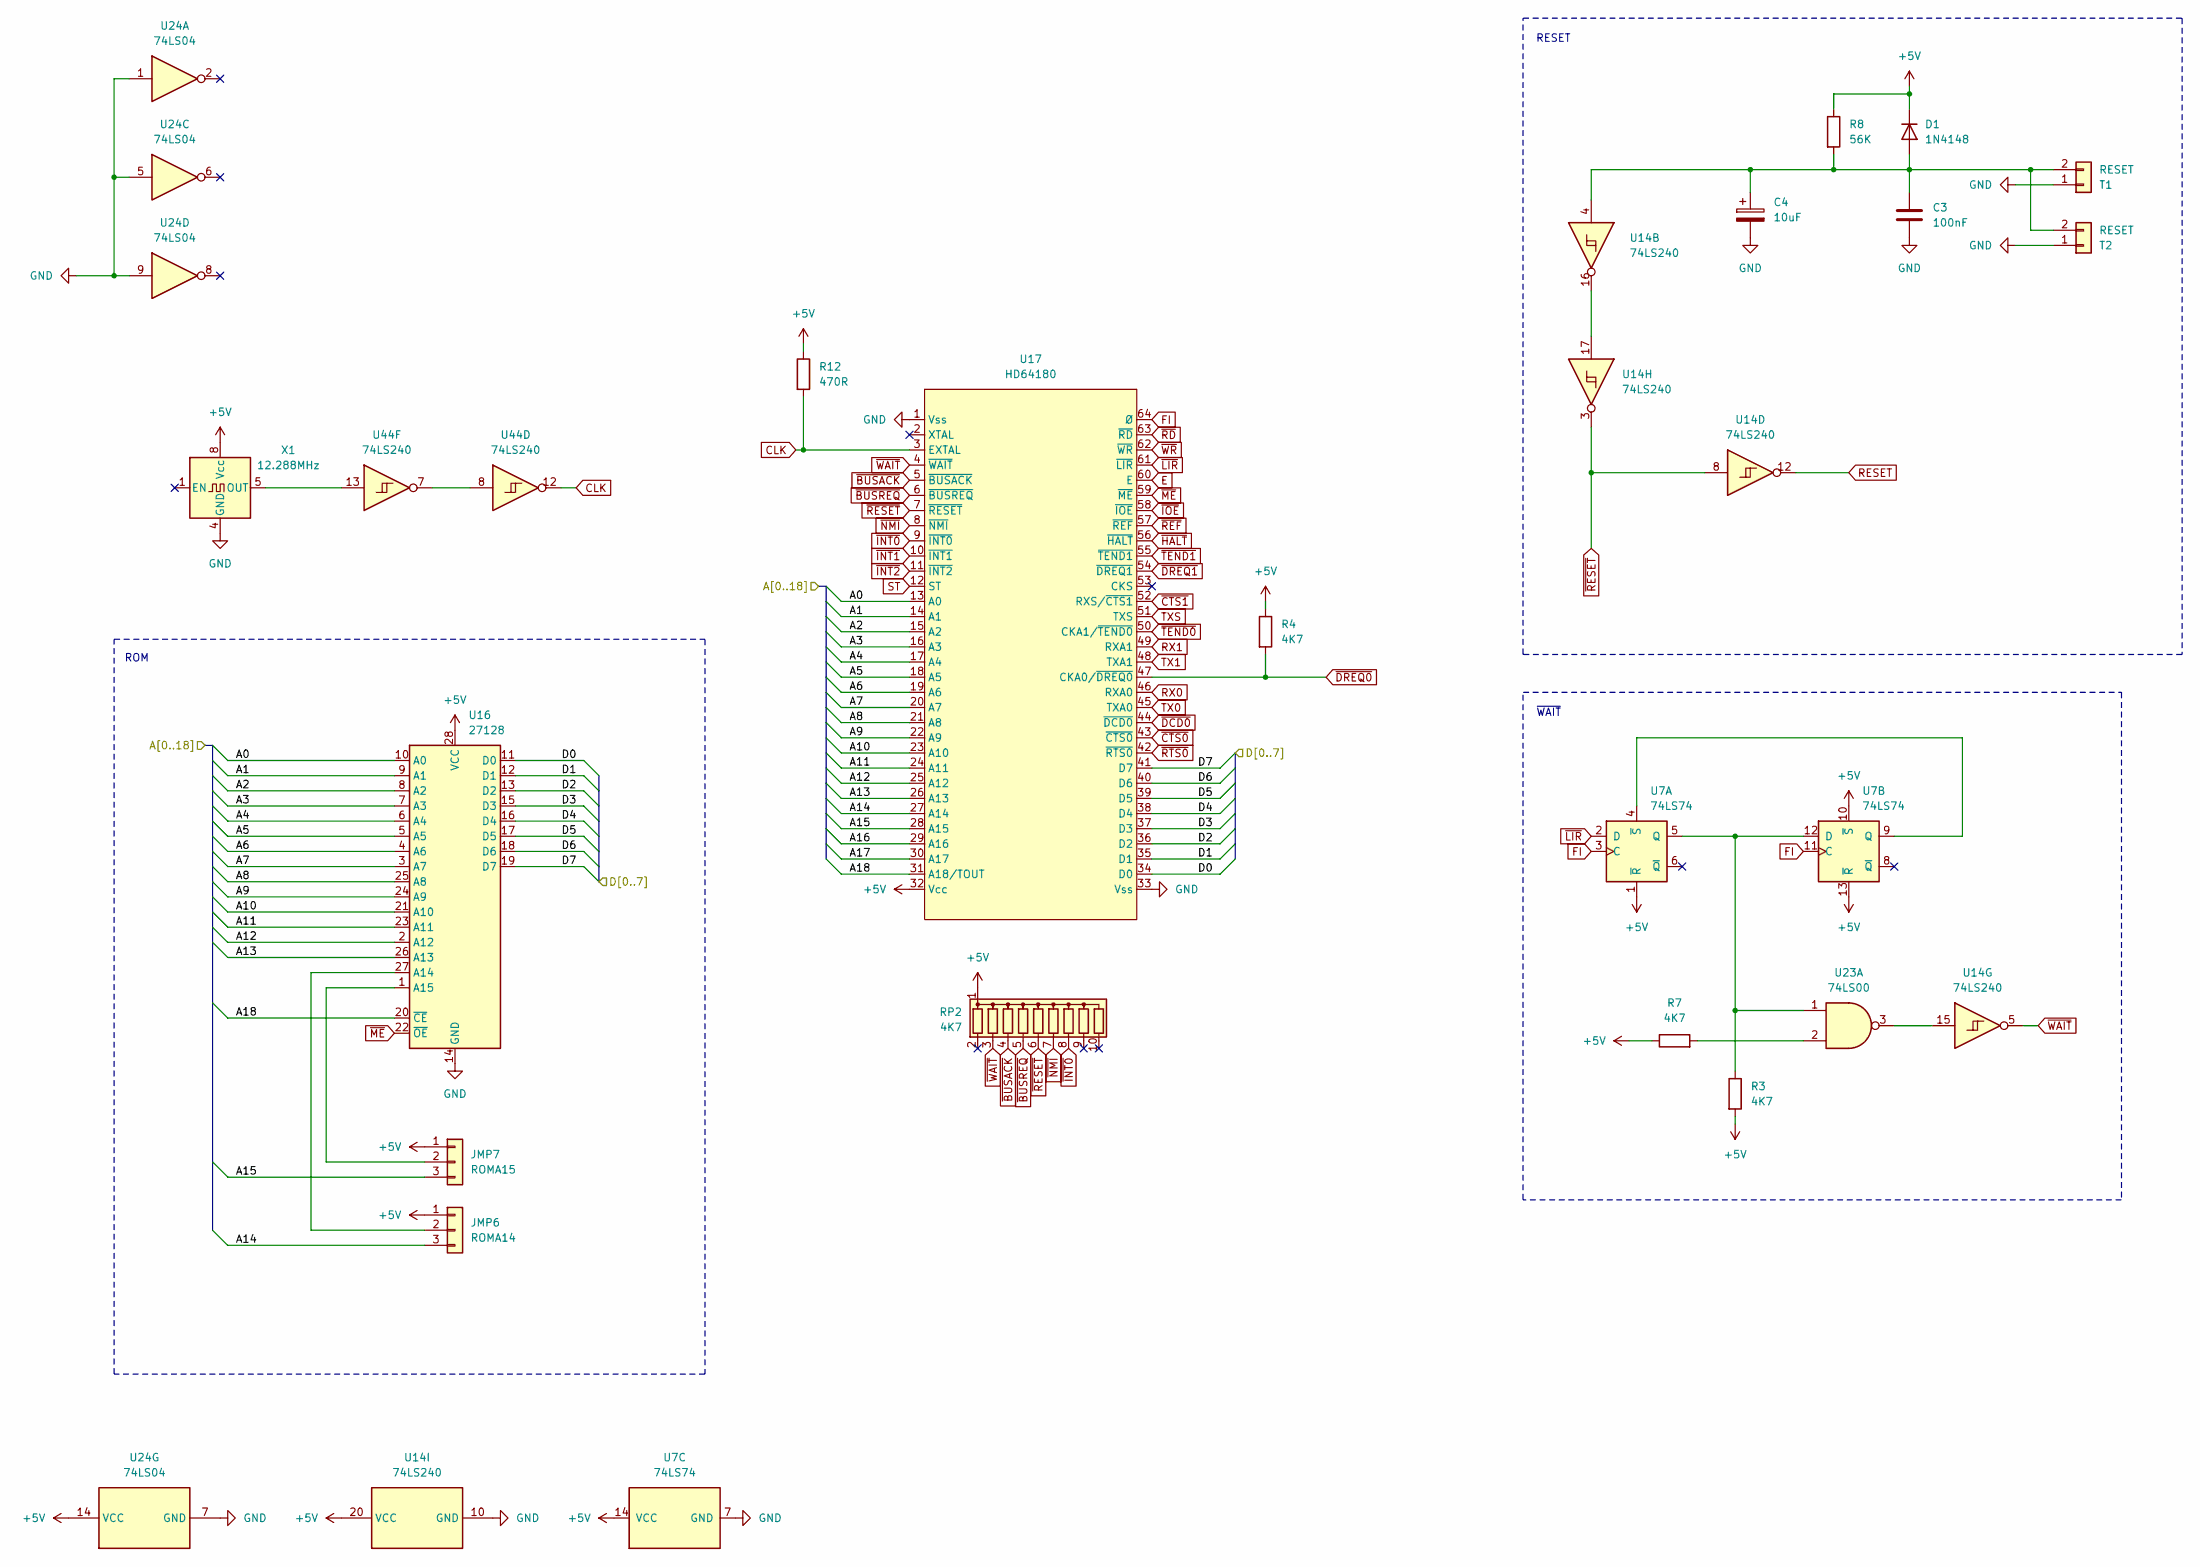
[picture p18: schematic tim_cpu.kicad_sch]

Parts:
C3: 100nF; Ceramic Cap 5.08mm
C4: 10uF; Electrolytic Capacitor Axial or Radial Alt
D1: 1N4148; Diode 10.16mm
JMP6: ROMA14; PinHeader_1x03 2.54mm
JMP7: ROMA15; PinHeader_1x03 2.54mm
R3, R4, R7: 4K7; Resistor 12.7mm
R8: 56K; Resistor 12.7mm
R12: 470R; Resistor 12.7mm
RP2: 4K7; R_Array_SIP10
T1: RESET; TP1
T2: RESET; SW_Tactile_SPST_Angled_PTS645Vx58-2LFS
U7: 74LS74; DIP-14_W7.62mm
U14, U44: 74LS240; DIP-20_W7.62mm
U16: 27128; DIP-28_W15.24mm_Socket
U17: HD64180; DIP-64_1.78mm Pitch_Socket
U23: 74LS00; DIP-14_W7.62mm
U24: 74LS04; DIP-14_W7.62mm
X1: 12.288MHz; TIM_Oscillator_DIP-8

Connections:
+5V: D1.1 (K), JMP6.1, JMP7.1, R3.2, R4.1, R7.1, R8.1, R12.1, RP2.1 (common), U7.1 (~R), U7.10 (~S), U7.13 (~R), U7.14 (VCC), U14.20 (VCC), U16.28 (VCC), U17.32 (Vcc), U24.14 (VCC), X1.8 (Vcc); also elsewhere on the board
/Addressing/A0: U16.10 (A0), U17.13 (A0); also elsewhere on the board
/Addressing/A1: U16.9 (A1), U17.14 (A1); also elsewhere on the board
/Addressing/A2: U16.8 (A2), U17.15 (A2); also elsewhere on the board
/Addressing/A3: U16.7 (A3), U17.16 (A3); also elsewhere on the board
/Addressing/A4: U16.6 (A4), U17.17 (A4); also elsewhere on the board
/Addressing/A5: U16.5 (A5), U17.18 (A5); also elsewhere on the board
/Addressing/A6: U16.4 (A6), U17.19 (A6); also elsewhere on the board
/Addressing/A7: U16.3 (A7), U17.20 (A7); also elsewhere on the board
/Addressing/A8: U16.25 (A8), U17.21 (A8); also elsewhere on the board
/Addressing/A9: U16.24 (A9), U17.22 (A9); also elsewhere on the board
/Addressing/A10: U16.21 (A10), U17.23 (A10); also elsewhere on the board
/Addressing/A11: U16.23 (A11), U17.24 (A11); also elsewhere on the board
/Addressing/A12: U16.2 (A12), U17.25 (A12); also elsewhere on the board
/Addressing/A13: U16.26 (A13), U17.26 (A13); also elsewhere on the board
/Addressing/A14: JMP6.3, U17.27 (A14); also elsewhere on the board
/Addressing/A15: JMP7.3, U17.28 (A15); also elsewhere on the board
/Addressing/A16: U17.29 (A16); also elsewhere on the board
/Addressing/A17: U17.30 (A17); also elsewhere on the board
/Addressing/A18: U16.20 (~CE), U17.31 (A18/TOUT); also elsewhere on the board
/CPU/D0: U16.11 (D0), U17.34 (D0); also elsewhere on the board
/CPU/D1: U16.12 (D1), U17.35 (D1); also elsewhere on the board
/CPU/D2: U16.13 (D2), U17.36 (D2); also elsewhere on the board
/CPU/D3: U16.15 (D3), U17.37 (D3); also elsewhere on the board
/CPU/D4: U16.16 (D4), U17.38 (D4); also elsewhere on the board
/CPU/D5: U16.17 (D5), U17.39 (D5); also elsewhere on the board
/CPU/D6: U16.18 (D6), U17.40 (D6); also elsewhere on the board
/CPU/D7: U16.19 (D7), U17.41 (D7); also elsewhere on the board
CLK: R12.2, U17.3 (EXTAL), U44.12; also elsewhere on the board
E: U17.60 (E); also elsewhere on the board
FI: U7.3 (C), U7.11 (C), U17.64 (Ø); also elsewhere on the board
GND: C3.2, C4.2, T1.1, T2.1, U7.7 (GND), U14.10 (GND), U16.14 (GND), U17.1 (Vss), U17.33 (Vss), U24.1, U24.5, U24.7 (GND), U24.9, X1.4 (GND); also elsewhere on the board
unnamed: C3.1, C4.1, D1.2 (A), R8.2, T1.2, T2.2, U14.4
unnamed: JMP6.2, U16.27 (A14)
unnamed: JMP7.2, U16.1 (A15)
unnamed: R7.2, U23.2
unnamed: R3.1, U7.5 (Q), U7.12 (D), U23.1
unnamed: U7.4 (~S), U7.9 (Q)
unnamed: U14.15, U23.3
unnamed: U14.16, U14.17
unnamed: U44.7, U44.8
unnamed: U44.13, X1.5 (OUT)
RESET: U14.12; also elsewhere on the board
RX0: U17.46 (RXA0); also elsewhere on the board
RX1: U17.49 (RXA1); also elsewhere on the board
ST: U17.12 (ST); also elsewhere on the board
TX0: U17.45 (TXA0); also elsewhere on the board
TX1: U17.48 (TXA1); also elsewhere on the board
TXS: U17.51 (TXS); also elsewhere on the board
~BUSACK: RP2.4 (R3), U17.5 (~BUSACK)
~BUSREQ: RP2.5 (R4), U17.6 (~BUSREQ)
~CTS0: U17.43 (~CTS0); also elsewhere on the board
~CTS1: U17.52 (RXS/~CTS1); also elsewhere on the board
~DCD0: U17.44 (~DCD0); also elsewhere on the board
~DREQ0: R4.2, U17.47 (CKA0/~DREQ0); also elsewhere on the board
~DREQ1: U17.54 (~DREQ1); also elsewhere on the board
~HALT: U17.56 (~HALT); also elsewhere on the board
~INT0: RP2.8 (R7), U17.9 (~INT0); also elsewhere on the board
~INT1: U17.10 (~INT1); also elsewhere on the board
~INT2: U17.11 (~INT2); also elsewhere on the board
~IOE: U17.58 (~IOE); also elsewhere on the board
~LIR: U7.2 (D), U17.61 (~LIR); also elsewhere on the board
~ME: U16.22 (~OE), U17.59 (~ME); also elsewhere on the board
~NMI: RP2.7 (R6), U17.8 (~NMI); also elsewhere on the board
~RD: U17.63 (~RD); also elsewhere on the board
~REF: U17.57 (~REF); also elsewhere on the board
~RESET: RP2.6 (R5), U14.3, U14.8, U17.7 (~RESET); also elsewhere on the board
~RTS0: U17.42 (~RTS0); also elsewhere on the board
~TEND0: U17.50 (CKA1/~TEND0); also elsewhere on the board
~TEND1: U17.55 (~TEND1); also elsewhere on the board
~WAIT: RP2.3 (R2), U14.5, U17.4 (~WAIT); also elsewhere on the board
~WR: U17.62 (~WR); also elsewhere on the board

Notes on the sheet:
ROM
RESET
~{WAIT}

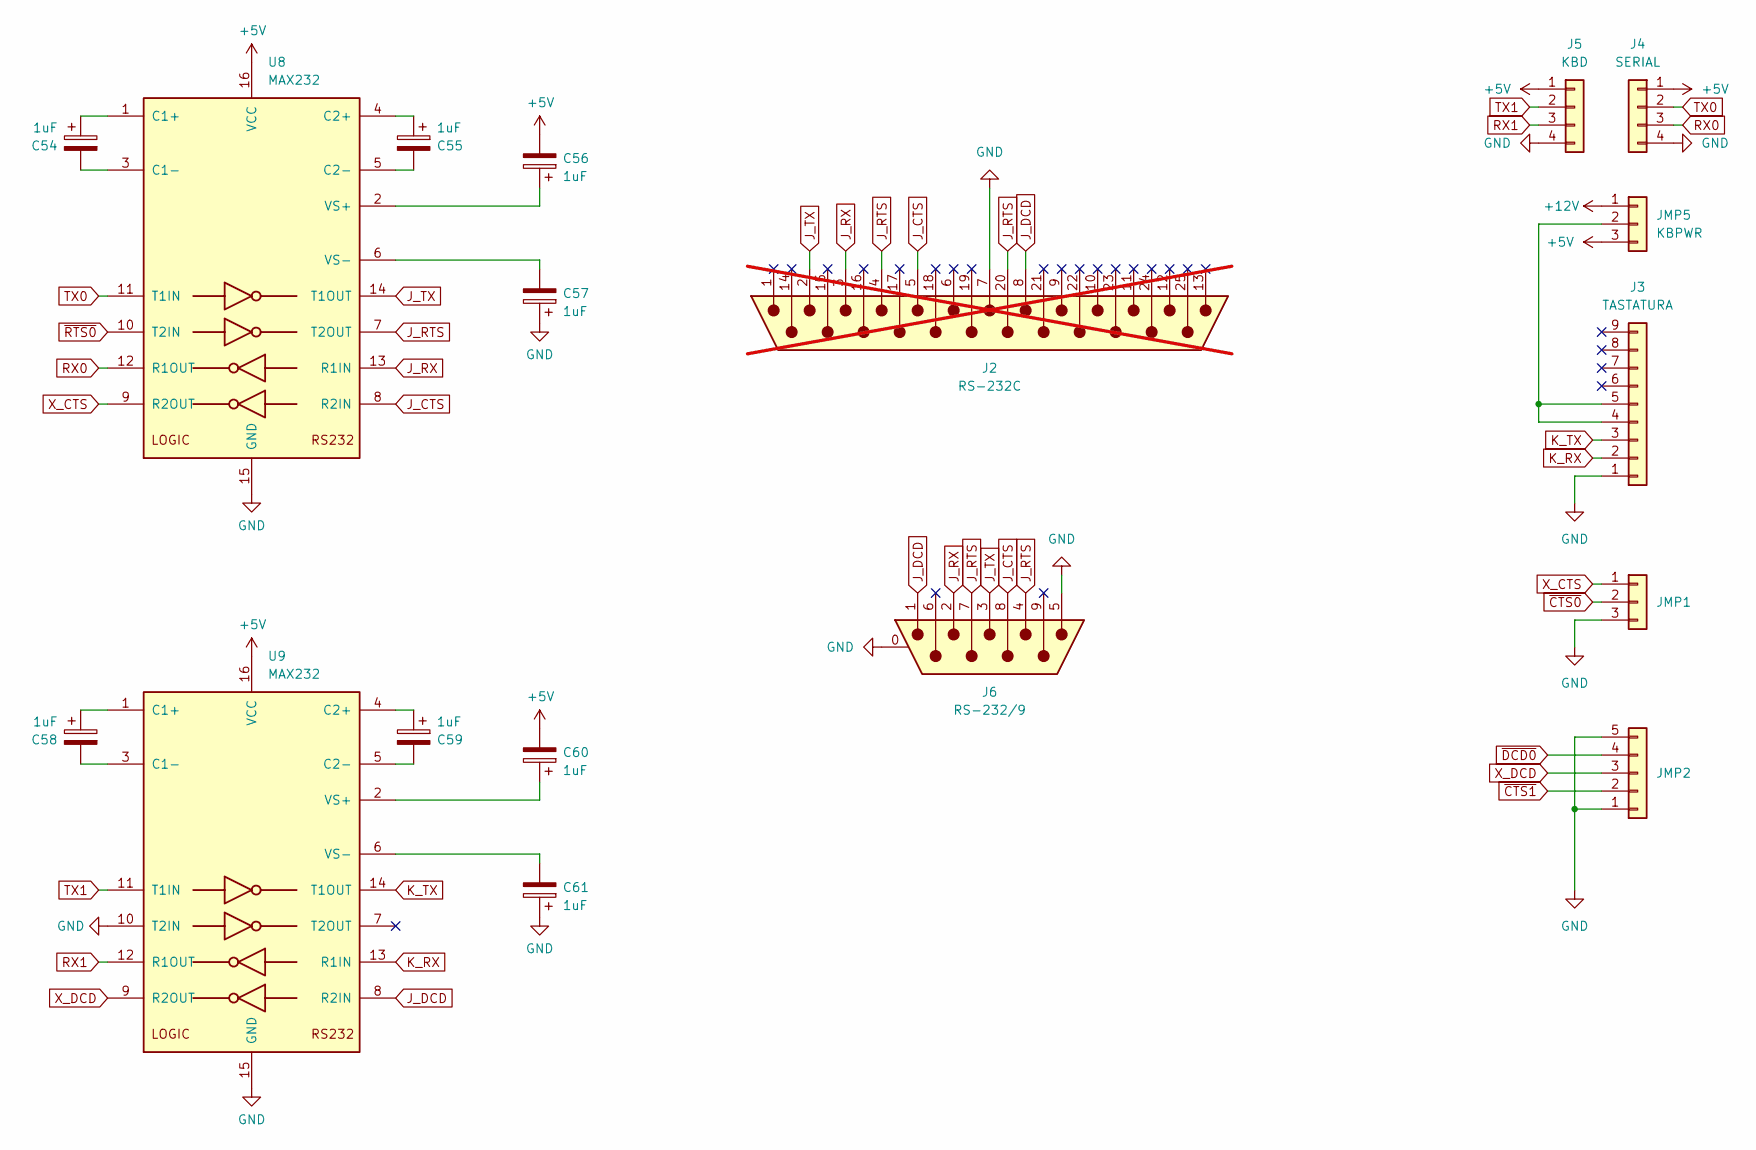
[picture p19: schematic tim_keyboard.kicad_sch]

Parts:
C54, C55, C56, C57, C58, C59, C60, C61: 1uF; Electrolytic Capacitor Radial
J2: RS-232C; RS232C; not fitted
J3: TASTATURA; KEYBOARD2
J4: SERIAL; PinHeader_1x04_2.54mm
J5: KBD; PinHeader_1x04_2.54mm
J6: RS-232/9; SERIAL9
JMP1: Conn_01x03; PinHeader_1x03 2.54mm
JMP2: PinHeader_1x05_2.54mm_Alt
JMP5: KBPWR; PinHeader_1x03 2.54mm
U8, U9: MAX232; DIP-16_W7.62mm

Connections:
+5V: C56.2, C60.2, J4.1, J5.1, JMP5.3, U8.16 (VCC), U9.16 (VCC); also elsewhere on the board
+12V: JMP5.1; also elsewhere on the board
GND: C57.1, C61.1, J2.7, J3.1, J4.4, J5.4, J6.0 (PAD), J6.5, JMP1.3, JMP2.1, JMP2.5, U8.15 (GND), U9.10 (T2IN), U9.15 (GND); also elsewhere on the board
J_CTS: J2.5, J6.8, U8.8 (R2IN)
J_DCD: J2.8, J6.1, U9.8 (R2IN)
J_RTS: J2.4, J2.20, J6.4, J6.7, U8.7 (T2OUT)
J_RX: J2.3, J6.2, U8.13 (R1IN)
J_TX: J2.2, J6.3, U8.14 (T1OUT)
K_RX: J3.2, U9.13 (R1IN)
K_TX: J3.3, U9.14 (T1OUT)
unnamed: J3.4, J3.5, JMP5.2
unnamed: C54.1, U8.1 (C1+)
unnamed: C54.2, U8.3 (C1-)
unnamed: C55.1, U8.4 (C2+)
unnamed: C55.2, U8.5 (C2-)
unnamed: C56.1, U8.2 (VS+)
unnamed: C57.2, U8.6 (VS-)
unnamed: C58.1, U9.1 (C1+)
unnamed: C58.2, U9.3 (C1-)
unnamed: C59.1, U9.4 (C2+)
unnamed: C59.2, U9.5 (C2-)
unnamed: C60.1, U9.2 (VS+)
unnamed: C61.2, U9.6 (VS-)
RX0: J4.3, U8.12 (R1OUT); also elsewhere on the board
RX1: J5.3, U9.12 (R1OUT); also elsewhere on the board
TX0: J4.2, U8.11 (T1IN); also elsewhere on the board
TX1: J5.2, U9.11 (T1IN); also elsewhere on the board
X_CTS: JMP1.1, U8.9 (R2OUT)
X_DCD: JMP2.3, U9.9 (R2OUT)
~CTS0: JMP1.2; also elsewhere on the board
~CTS1: JMP2.2; also elsewhere on the board
~DCD0: JMP2.4; also elsewhere on the board
~RTS0: U8.10 (T2IN); also elsewhere on the board

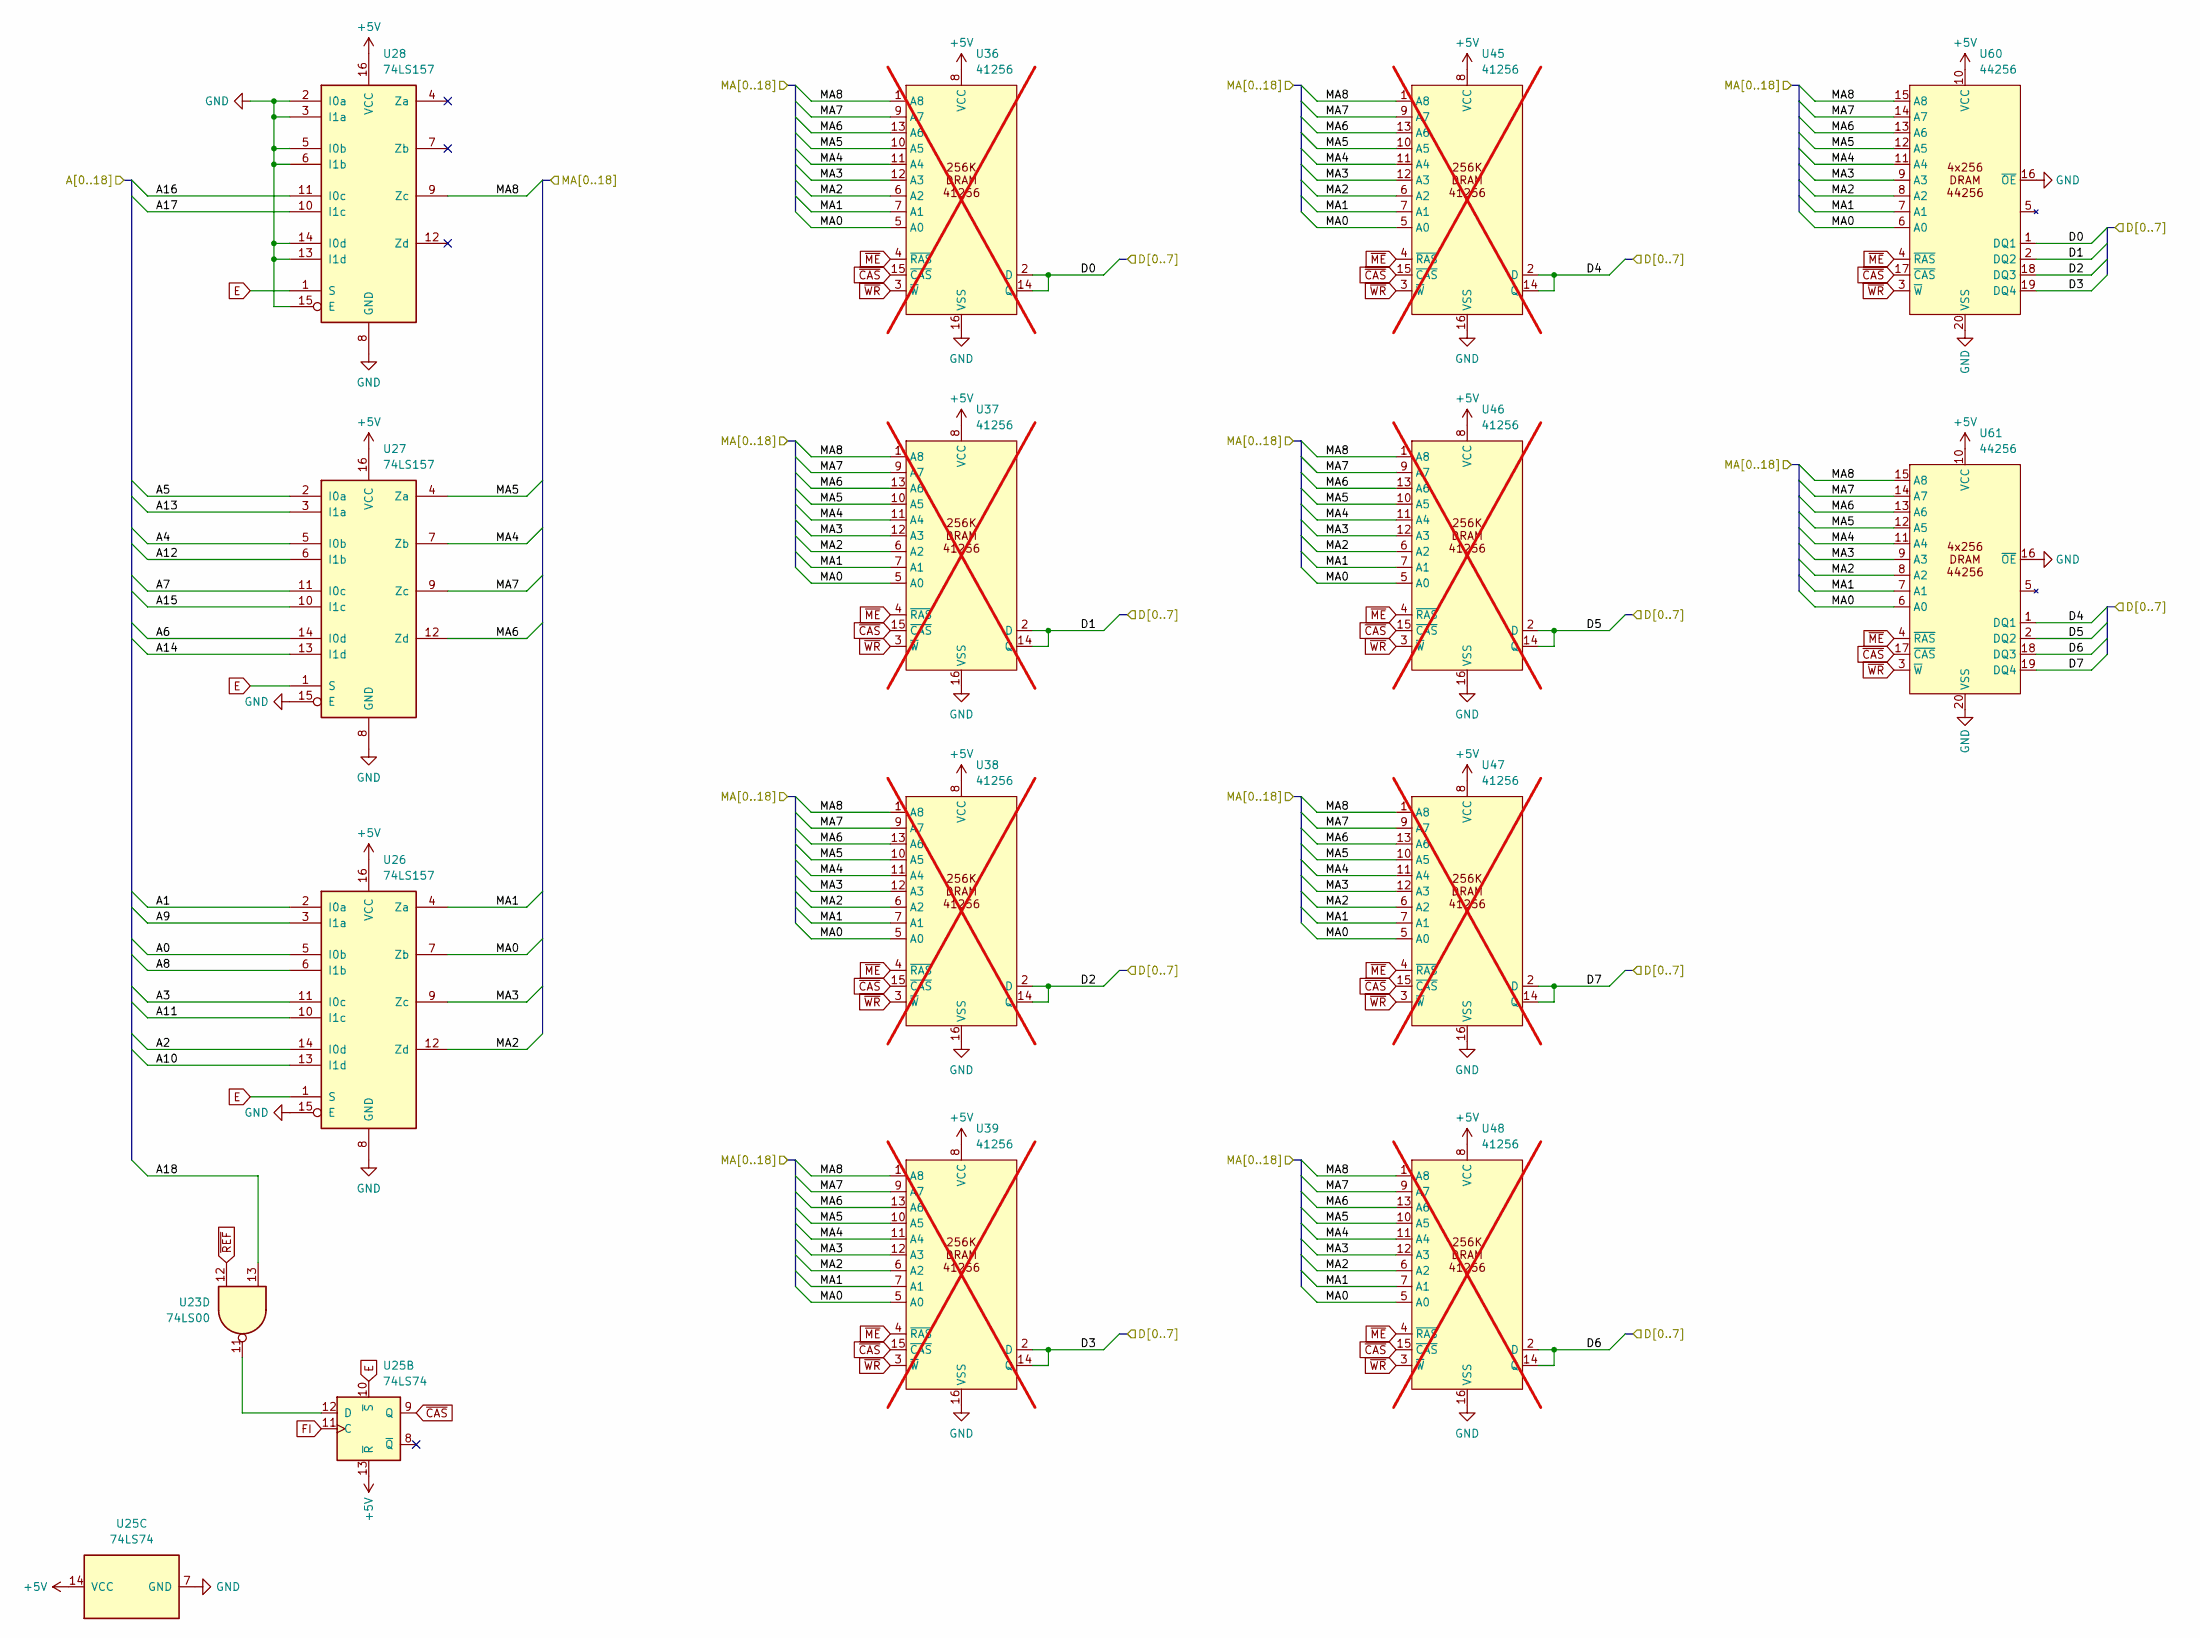
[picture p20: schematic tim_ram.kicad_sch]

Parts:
U23: 74LS00; DIP-14_W7.62mm
U25: 74LS74; DIP-14_W7.62mm
U26, U27, U28: 74LS157; DIP-16_W7.62mm
U36, U37, U38, U39, U45, U46, U47, U48: 41256; DIP-16_W7.62mm_Socket; not fitted
U60, U61: 44256; DIP-20_W7.62mm

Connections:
+5V: U25.13 (~R), U25.14 (VCC), U26.16 (VCC), U27.16 (VCC), U28.16 (VCC), U36.8 (VCC), U37.8 (VCC), U38.8 (VCC), U39.8 (VCC), U45.8 (VCC), U46.8 (VCC), U47.8 (VCC), U48.8 (VCC), U60.10 (VCC), U61.10 (VCC); also elsewhere on the board
/Addressing/A0: U26.5 (I0b); also elsewhere on the board
/Addressing/A1: U26.2 (I0a); also elsewhere on the board
/Addressing/A2: U26.14 (I0d); also elsewhere on the board
/Addressing/A3: U26.11 (I0c); also elsewhere on the board
/Addressing/A4: U27.5 (I0b); also elsewhere on the board
/Addressing/A5: U27.2 (I0a); also elsewhere on the board
/Addressing/A6: U27.14 (I0d); also elsewhere on the board
/Addressing/A7: U27.11 (I0c); also elsewhere on the board
/Addressing/A8: U26.6 (I1b); also elsewhere on the board
/Addressing/A9: U26.3 (I1a); also elsewhere on the board
/Addressing/A10: U26.13 (I1d); also elsewhere on the board
/Addressing/A11: U26.10 (I1c); also elsewhere on the board
/Addressing/A12: U27.6 (I1b); also elsewhere on the board
/Addressing/A13: U27.3 (I1a); also elsewhere on the board
/Addressing/A14: U27.13 (I1d); also elsewhere on the board
/Addressing/A15: U27.10 (I1c); also elsewhere on the board
/Addressing/A16: U28.11 (I0c); also elsewhere on the board
/Addressing/A17: U28.10 (I1c); also elsewhere on the board
/Addressing/A18: U23.13; also elsewhere on the board
/CPU/D0: U36.2 (D), U36.14 (Q), U60.1 (DQ1); also elsewhere on the board
/CPU/D1: U37.2 (D), U37.14 (Q), U60.2 (DQ2); also elsewhere on the board
/CPU/D2: U38.2 (D), U38.14 (Q), U60.18 (DQ3); also elsewhere on the board
/CPU/D3: U39.2 (D), U39.14 (Q), U60.19 (DQ4); also elsewhere on the board
/CPU/D4: U45.2 (D), U45.14 (Q), U61.1 (DQ1); also elsewhere on the board
/CPU/D5: U46.2 (D), U46.14 (Q), U61.2 (DQ2); also elsewhere on the board
/CPU/D6: U48.2 (D), U48.14 (Q), U61.18 (DQ3); also elsewhere on the board
/CPU/D7: U47.2 (D), U47.14 (Q), U61.19 (DQ4); also elsewhere on the board
/RAM/MA0: U26.7 (Zb), U36.5 (A0), U37.5 (A0), U38.5 (A0), U39.5 (A0), U45.5 (A0), U46.5 (A0), U47.5 (A0), U48.5 (A0), U60.6 (A0), U61.6 (A0)
/RAM/MA1: U26.4 (Za), U36.7 (A1), U37.7 (A1), U38.7 (A1), U39.7 (A1), U45.7 (A1), U46.7 (A1), U47.7 (A1), U48.7 (A1), U60.7 (A1), U61.7 (A1)
/RAM/MA2: U26.12 (Zd), U36.6 (A2), U37.6 (A2), U38.6 (A2), U39.6 (A2), U45.6 (A2), U46.6 (A2), U47.6 (A2), U48.6 (A2), U60.8 (A2), U61.8 (A2)
/RAM/MA3: U26.9 (Zc), U36.12 (A3), U37.12 (A3), U38.12 (A3), U39.12 (A3), U45.12 (A3), U46.12 (A3), U47.12 (A3), U48.12 (A3), U60.9 (A3), U61.9 (A3)
/RAM/MA4: U27.7 (Zb), U36.11 (A4), U37.11 (A4), U38.11 (A4), U39.11 (A4), U45.11 (A4), U46.11 (A4), U47.11 (A4), U48.11 (A4), U60.11 (A4), U61.11 (A4)
/RAM/MA5: U27.4 (Za), U36.10 (A5), U37.10 (A5), U38.10 (A5), U39.10 (A5), U45.10 (A5), U46.10 (A5), U47.10 (A5), U48.10 (A5), U60.12 (A5), U61.12 (A5)
/RAM/MA6: U27.12 (Zd), U36.13 (A6), U37.13 (A6), U38.13 (A6), U39.13 (A6), U45.13 (A6), U46.13 (A6), U47.13 (A6), U48.13 (A6), U60.13 (A6), U61.13 (A6)
/RAM/MA7: U27.9 (Zc), U36.9 (A7), U37.9 (A7), U38.9 (A7), U39.9 (A7), U45.9 (A7), U46.9 (A7), U47.9 (A7), U48.9 (A7), U60.14 (A7), U61.14 (A7)
/RAM/MA8: U28.9 (Zc), U36.1 (A8), U37.1 (A8), U38.1 (A8), U39.1 (A8), U45.1 (A8), U46.1 (A8), U47.1 (A8), U48.1 (A8), U60.15 (A8), U61.15 (A8)
E: U25.10 (~S), U26.1 (S), U27.1 (S), U28.1 (S); also elsewhere on the board
FI: U25.11 (C); also elsewhere on the board
GND: U25.7 (GND), U26.8 (GND), U26.15 (E), U27.8 (GND), U27.15 (E), U28.2 (I0a), U28.3 (I1a), U28.5 (I0b), U28.6 (I1b), U28.8 (GND), U28.13 (I1d), U28.14 (I0d), U28.15 (E), U36.16 (VSS), U37.16 (VSS), U38.16 (VSS), U39.16 (VSS), U45.16 (VSS), U46.16 (VSS), U47.16 (VSS), U48.16 (VSS), U60.16 (~OE), U60.20 (VSS), U61.16 (~OE), U61.20 (VSS); also elsewhere on the board
unnamed: U23.11, U25.12 (D)
~CAS: U25.9 (Q), U36.15 (~CAS), U37.15 (~CAS), U38.15 (~CAS), U39.15 (~CAS), U45.15 (~CAS), U46.15 (~CAS), U47.15 (~CAS), U48.15 (~CAS), U60.17 (~CAS), U61.17 (~CAS)
~ME: U36.4 (~RAS), U37.4 (~RAS), U38.4 (~RAS), U39.4 (~RAS), U45.4 (~RAS), U46.4 (~RAS), U47.4 (~RAS), U48.4 (~RAS), U60.4 (~RAS), U61.4 (~RAS); also elsewhere on the board
~REF: U23.12; also elsewhere on the board
~WR: U36.3 (~W), U37.3 (~W), U38.3 (~W), U39.3 (~W), U45.3 (~W), U46.3 (~W), U47.3 (~W), U48.3 (~W), U60.3 (~W), U61.3 (~W); also elsewhere on the board

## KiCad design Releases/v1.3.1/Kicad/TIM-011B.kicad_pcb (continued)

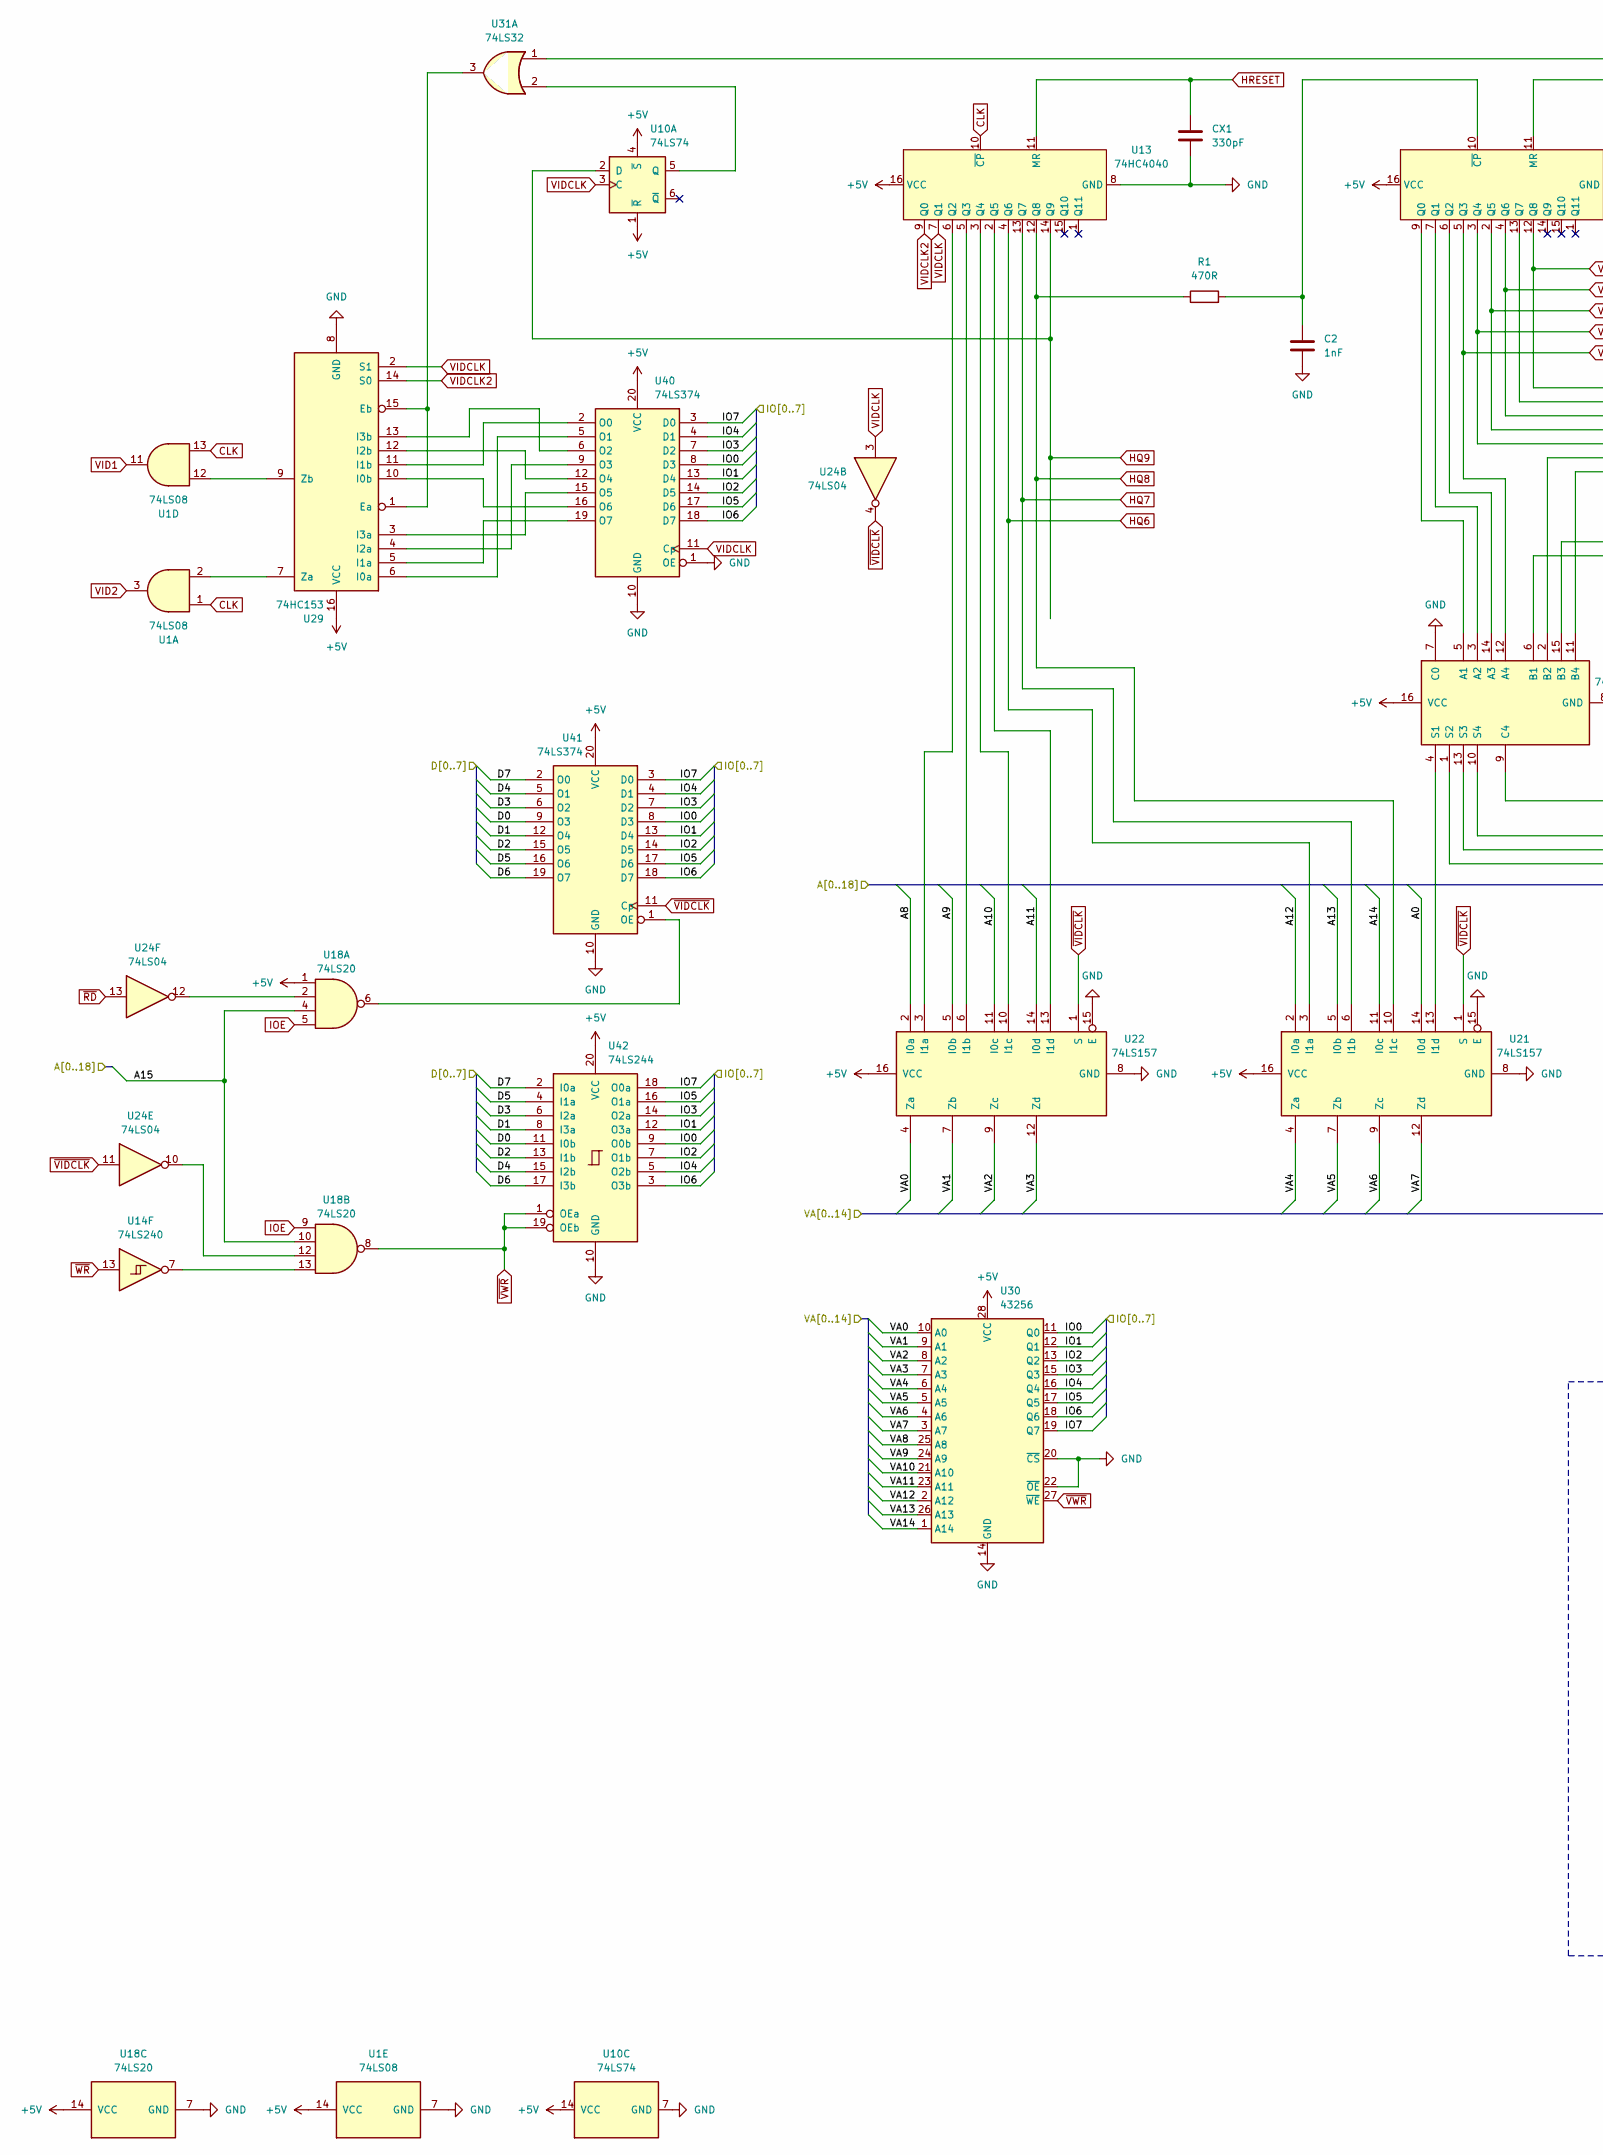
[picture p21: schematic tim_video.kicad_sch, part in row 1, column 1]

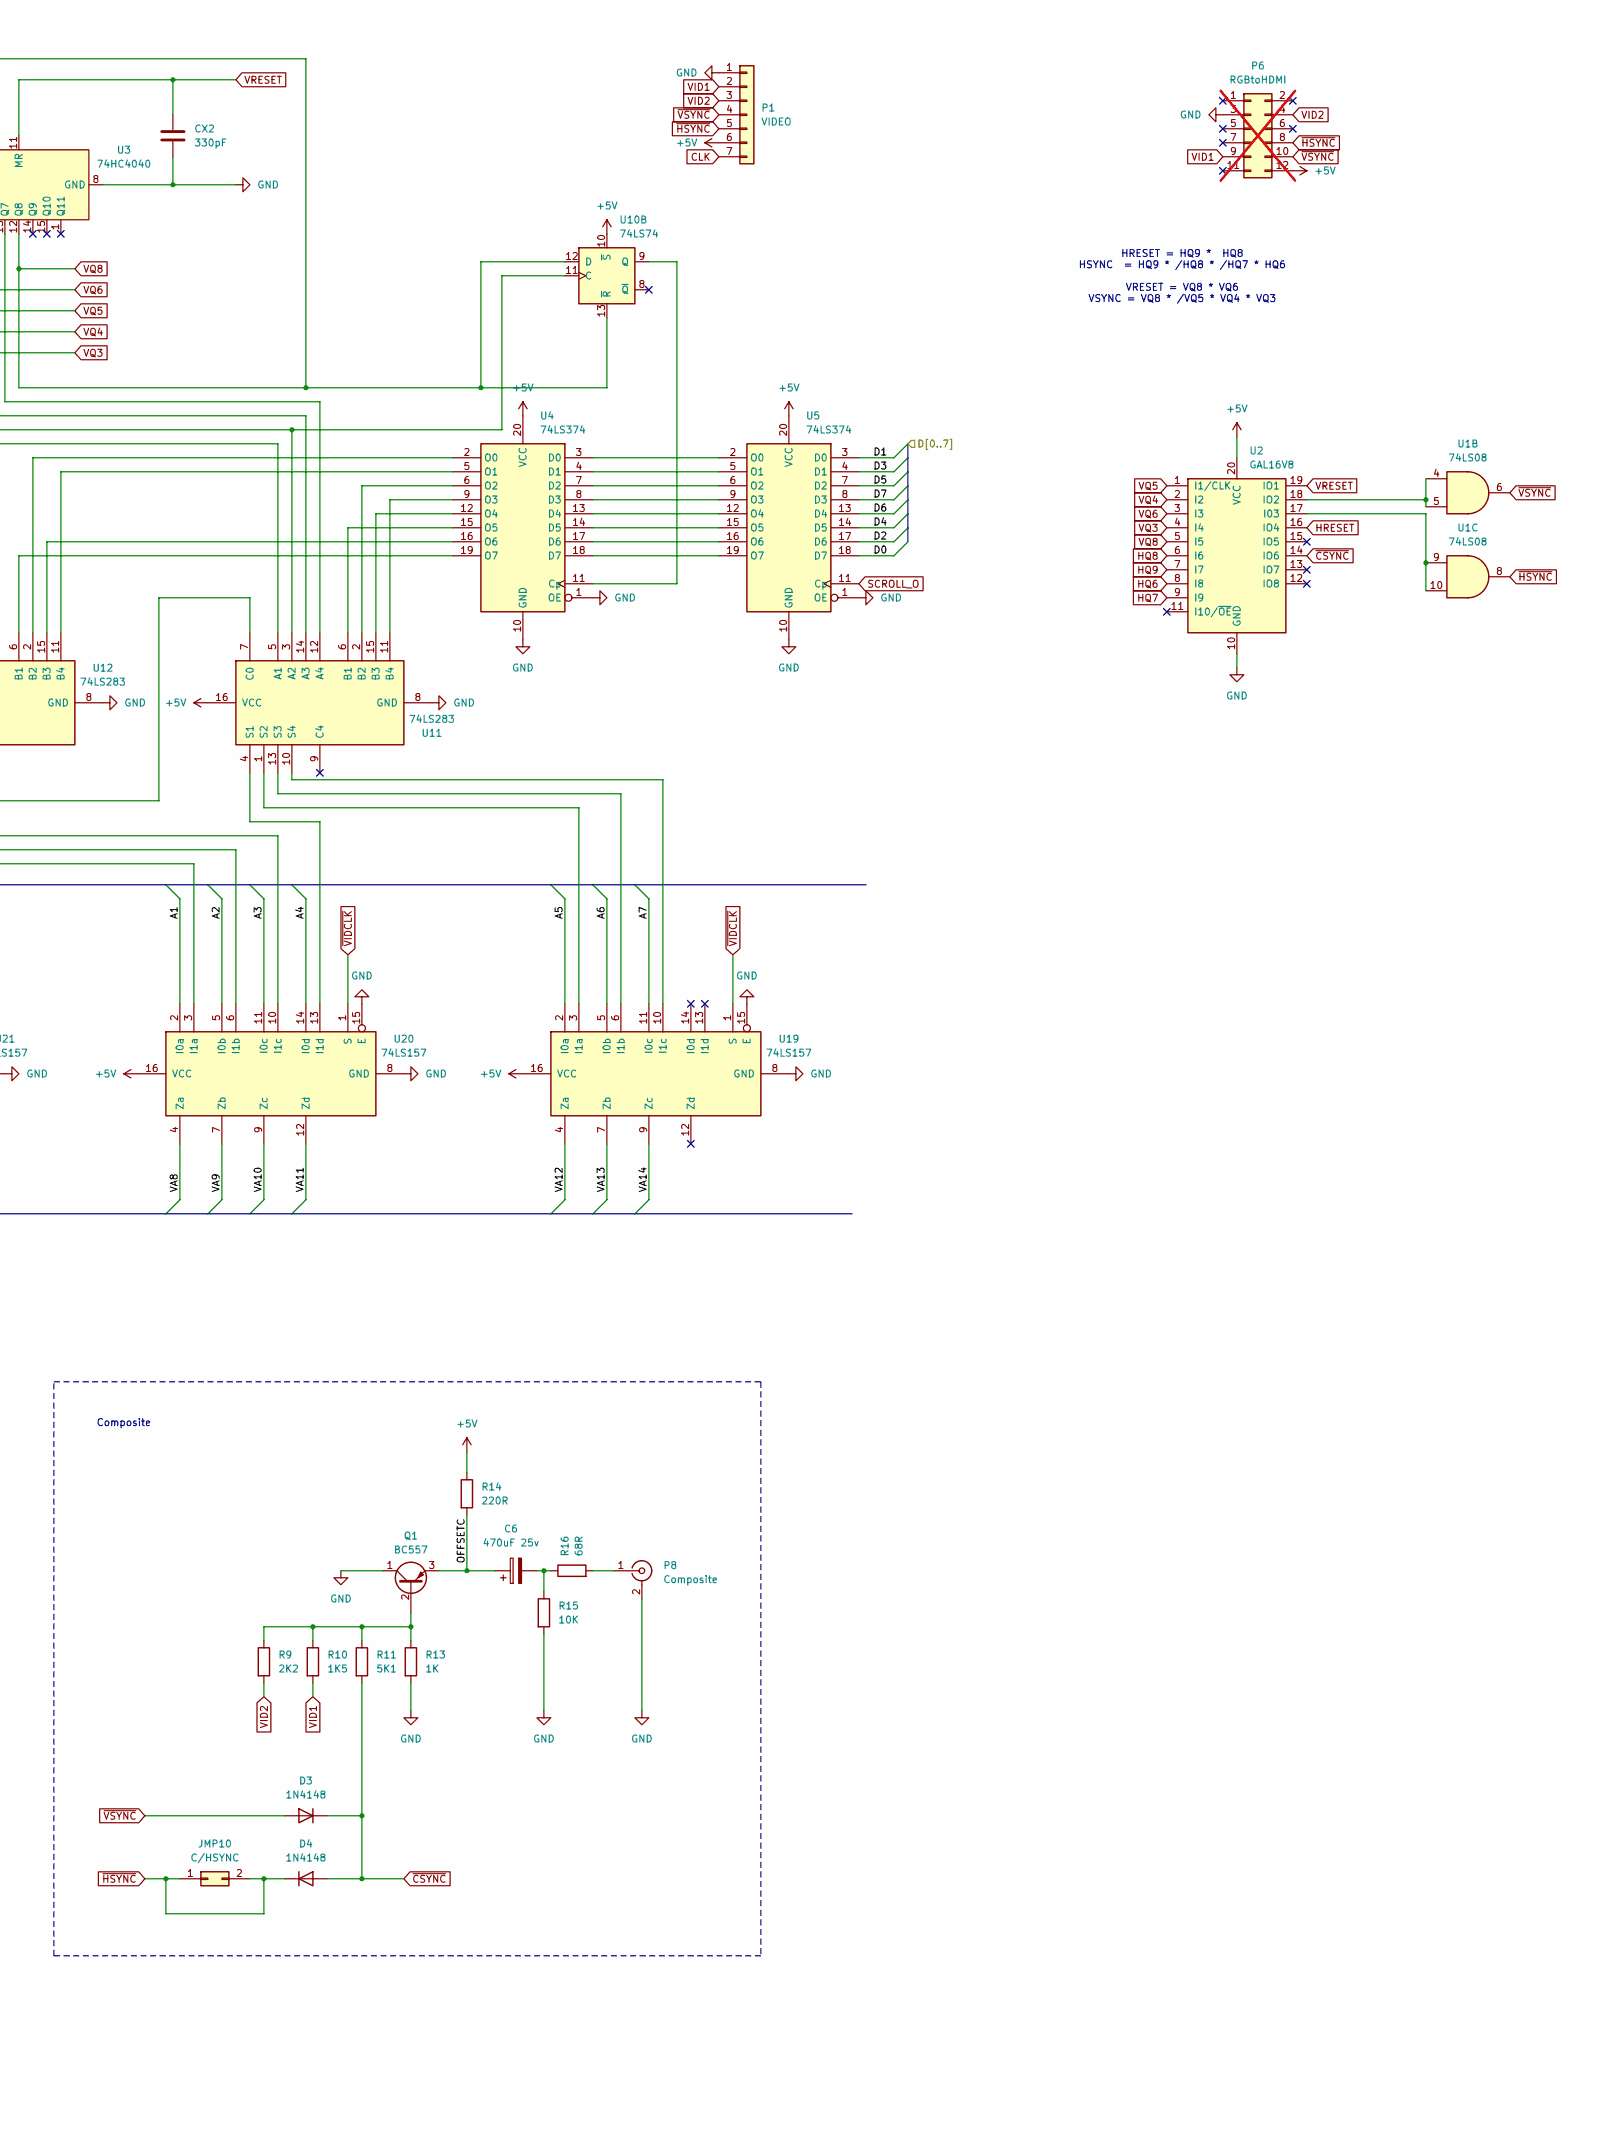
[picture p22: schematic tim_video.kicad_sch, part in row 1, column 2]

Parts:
C2: 1nF; Ceramic Cap 5.08mm
C6: 470uF 25v; Electrolytic Capacitor Axial or Radial Alt
CX1, CX2: 330pF; Ceramic Cap 5.08mm
D3, D4: 1N4148; Diode 10.16mm
JMP10: C/HSYNC; PinHeader_1x02 2.54mm
P1: VIDEO; PinHeader_1x07 2.54mm VIDEO
P6: RGBtoHDMI; PinSocket_2x06_P2.54mm_Vertical; not fitted
P8: Composite; RCA2
Q1: BC557; TO-92_Inline_Wide
R1: 470R; Resistor 12.7mm
R9: 2K2; Resistor 12.7mm
R10: 1K5; Resistor 12.7mm
R11: 5K1; Resistor 12.7mm
R13: 1K; Resistor 12.7mm
R14: 220R; Resistor 12.7mm
R15: 10K; Resistor 12.7mm
R16: 68R; Resistor 12.7mm
U1: 74LS08; DIP-14_W7.62mm
U2: GAL16V8; DIP-20_W7.62mm
U3, U13: 74HC4040; DIP-16_W7.62mm
U4, U5, U40, U41: 74LS374; DIP-20_W7.62mm
U10: 74LS74; DIP-14_W7.62mm
U11, U12: 74LS283; DIP-16_W7.62mm
U14: 74LS240; DIP-20_W7.62mm
U18: 74LS20; DIP-14_W7.62mm
U19, U20, U21, U22: 74LS157; DIP-16_W7.62mm
U24: 74LS04; DIP-14_W7.62mm
U29: 74HC153; DIP-16_W7.62mm
U30: 43256; DIP-28_W15.24mm_Socket
U31: 74LS32; DIP-14_W7.62mm
U42: 74LS244; DIP-20_W7.62mm

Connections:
+5V: P1.6, P6.12, R14.1, U1.14 (VCC), U2.20 (VCC), U3.16 (VCC), U4.20 (VCC), U5.20 (VCC), U10.1 (~R), U10.4 (~S), U10.10 (~S), U10.14 (VCC), U11.16 (VCC), U12.16 (VCC), U13.16 (VCC), U18.1, U18.14 (VCC), U19.16 (VCC), U20.16 (VCC), U21.16 (VCC), U22.16 (VCC), U29.16 (VCC), U30.28 (VCC), U40.20 (VCC), U41.20 (VCC), U42.20 (VCC); also elsewhere on the board
/Addressing/A0: U21.14 (I0d); also elsewhere on the board
/Addressing/A1: U20.2 (I0a); also elsewhere on the board
/Addressing/A2: U20.5 (I0b); also elsewhere on the board
/Addressing/A3: U20.11 (I0c); also elsewhere on the board
/Addressing/A4: U20.14 (I0d); also elsewhere on the board
/Addressing/A5: U19.2 (I0a); also elsewhere on the board
/Addressing/A6: U19.5 (I0b); also elsewhere on the board
/Addressing/A7: U19.11 (I0c); also elsewhere on the board
/Addressing/A8: U22.2 (I0a); also elsewhere on the board
/Addressing/A9: U22.5 (I0b); also elsewhere on the board
/Addressing/A10: U22.11 (I0c); also elsewhere on the board
/Addressing/A11: U22.14 (I0d); also elsewhere on the board
/Addressing/A12: U21.2 (I0a); also elsewhere on the board
/Addressing/A13: U21.5 (I0b); also elsewhere on the board
/Addressing/A14: U21.11 (I0c); also elsewhere on the board
/Addressing/A15: U18.4, U18.10; also elsewhere on the board
/CPU/D0: U5.18 (D7), U41.9 (O3), U42.11 (I0b); also elsewhere on the board
/CPU/D1: U5.3 (D0), U41.12 (O4), U42.8 (I3a); also elsewhere on the board
/CPU/D2: U5.17 (D6), U41.15 (O5), U42.13 (I1b); also elsewhere on the board
/CPU/D3: U5.4 (D1), U41.6 (O2), U42.6 (I2a); also elsewhere on the board
/CPU/D4: U5.14 (D5), U41.5 (O1), U42.15 (I2b); also elsewhere on the board
/CPU/D5: U5.7 (D2), U41.16 (O6), U42.4 (I1a); also elsewhere on the board
/CPU/D6: U5.13 (D4), U41.19 (O7), U42.17 (I3b); also elsewhere on the board
/CPU/D7: U5.8 (D3), U41.2 (O0), U42.2 (I0a); also elsewhere on the board
/Video/IO0: U30.11 (Q0), U40.8 (D3), U41.8 (D3), U42.9 (O0b)
/Video/IO1: U30.12 (Q1), U40.13 (D4), U41.13 (D4), U42.12 (O3a)
/Video/IO2: U30.13 (Q2), U40.14 (D5), U41.14 (D5), U42.7 (O1b)
/Video/IO3: U30.15 (Q3), U40.7 (D2), U41.7 (D2), U42.14 (O2a)
/Video/IO4: U30.16 (Q4), U40.4 (D1), U41.4 (D1), U42.5 (O2b)
/Video/IO5: U30.17 (Q5), U40.17 (D6), U41.17 (D6), U42.16 (O1a)
/Video/IO6: U30.18 (Q6), U40.18 (D7), U41.18 (D7), U42.3 (O3b)
/Video/IO7: U30.19 (Q7), U40.3 (D0), U41.3 (D0), U42.18 (O0a)
/Video/OFFSETC: C6.1, Q1.3 (E), R14.2
/Video/VA0: U22.4 (Za), U30.10 (A0)
/Video/VA1: U22.7 (Zb), U30.9 (A1)
/Video/VA2: U22.9 (Zc), U30.8 (A2)
/Video/VA3: U22.12 (Zd), U30.7 (A3)
/Video/VA4: U21.4 (Za), U30.6 (A4)
/Video/VA5: U21.7 (Zb), U30.5 (A5)
/Video/VA6: U21.9 (Zc), U30.4 (A6)
/Video/VA7: U21.12 (Zd), U30.3 (A7)
/Video/VA8: U20.4 (Za), U30.25 (A8)
/Video/VA9: U20.7 (Zb), U30.24 (A9)
/Video/VA10: U20.9 (Zc), U30.21 (A10)
/Video/VA11: U20.12 (Zd), U30.23 (A11)
/Video/VA12: U19.4 (Za), U30.2 (A12)
/Video/VA13: U19.7 (Zb), U30.26 (A13)
/Video/VA14: U19.9 (Zc), U30.1 (A14)
CLK: P1.7, U1.1, U1.13, U13.10 (~CP); also elsewhere on the board
GND: C2.2, CX1.2, CX2.2, P1.1, P6.3, P8.2 (Ext), Q1.1 (C), R13.2, R15.2, U1.7 (GND), U2.10 (GND), U3.8 (GND), U4.1 (OE), U4.10 (GND), U5.1 (OE), U5.10 (GND), U10.7 (GND), U11.8 (GND), U12.7 (C0), U12.8 (GND), U13.8 (GND), U18.7 (GND), U19.8 (GND), U19.15 (E), U20.8 (GND), U20.15 (E), U21.8 (GND), U21.15 (E), U22.8 (GND), U22.15 (E), U29.8 (GND), U30.14 (GND), U30.20 (~CS), U30.22 (~OE), U40.1 (OE), U40.10 (GND), U41.10 (GND), U42.10 (GND); also elsewhere on the board
HQ6: U2.8 (I8), U13.4 (Q6), U21.3 (I1a)
HQ7: U2.9 (I9), U13.13 (Q7), U21.6 (I1b)
HQ8: R1.1, U2.6 (I6), U13.12 (Q8), U21.10 (I1c)
HQ9: U2.7 (I7), U10.2 (D), U13.14 (Q9)
HRESET: CX1.1, U2.16 (IO4), U13.11 (MR)
IOE: U18.5, U18.9; also elsewhere on the board
unnamed: C6.2, R15.1, R16.1
unnamed: P8.1 (In), R16.2
unnamed: Q1.2 (B), R9.1, R10.1, R11.1, R13.1
unnamed: U1.9, U1.10, U2.17 (I03)
unnamed: U1.4, U1.5, U2.18 (IO2)
unnamed: C2.1, R1.2, U3.10 (~CP)
unnamed: U4.3 (D0), U5.2 (O0)
unnamed: U4.4 (D1), U5.5 (O1)
unnamed: U4.7 (D2), U5.6 (O2)
unnamed: U4.8 (D3), U5.9 (O3)
unnamed: U4.13 (D4), U5.12 (O4)
unnamed: U4.14 (D5), U5.15 (O5)
unnamed: U4.17 (D6), U5.16 (O6)
unnamed: U4.18 (D7), U5.19 (O7)
unnamed: U10.5 (Q), U31.2
unnamed: U4.11 (Cp), U10.9 (Q)
unnamed: U3.13 (Q7), U11.12 (A4)
unnamed: U4.15 (O5), U11.6 (B1)
unnamed: U4.6 (O2), U11.2 (B2)
unnamed: U4.12 (O4), U11.15 (B3)
unnamed: U4.9 (O3), U11.11 (B4)
unnamed: U11.7 (C0), U12.9 (C4)
unnamed: U11.4 (S1), U20.13 (I1d)
unnamed: U11.1 (S2), U19.3 (I1a)
unnamed: U11.13 (S3), U19.6 (I1b)
unnamed: U11.10 (S4), U19.10 (I1c)
unnamed: U3.9 (Q0), U12.5 (A1)
unnamed: U3.7 (Q1), U12.3 (A2)
unnamed: U3.6 (Q2), U12.14 (A3)
unnamed: U4.19 (O7), U12.6 (B1)
unnamed: U4.2 (O0), U12.2 (B2)
unnamed: U4.16 (O6), U12.15 (B3)
unnamed: U4.5 (O1), U12.11 (B4)
unnamed: U12.4 (S1), U21.13 (I1d)
unnamed: U12.1 (S2), U20.3 (I1a)
unnamed: U12.13 (S3), U20.6 (I1b)
unnamed: U12.10 (S4), U20.10 (I1c)
unnamed: U13.6 (Q2), U22.3 (I1a)
unnamed: U13.5 (Q3), U22.6 (I1b)
unnamed: U13.3 (Q4), U22.10 (I1c)
unnamed: U13.2 (Q5), U22.13 (I1d)
unnamed: U14.7, U18.13
unnamed: U18.2, U24.12
unnamed: U18.12, U24.10
unnamed: U29.1 (Ea), U29.15 (Eb), U31.3
unnamed: U29.6 (I0a), U40.5 (O1)
unnamed: U29.10 (I0b), U40.16 (O6)
unnamed: U29.5 (I1a), U40.19 (O7)
unnamed: U29.11 (I1b), U40.2 (O0)
unnamed: U29.4 (I2a), U40.9 (O3)
unnamed: U29.12 (I2b), U40.12 (O4)
unnamed: U29.3 (I3a), U40.15 (O5)
unnamed: U29.13 (I3b), U40.6 (O2)
unnamed: U1.2, U29.7 (Za)
unnamed: U1.12, U29.9 (Zb)
unnamed: U18.6, U41.1 (OE)
SCROLL_O: U5.11 (Cp); also elsewhere on the board
VID1: P1.2, P6.9, R10.2, U1.11
VID2: P1.3, P6.4, R9.2, U1.3
VIDCLK: U10.3 (C), U13.7 (Q1), U24.3, U29.2 (S1), U40.11 (Cp)
VIDCLK2: U13.9 (Q0), U29.14 (S0)
VQ3: U2.4 (I4), U3.5 (Q3), U12.12 (A4)
VQ4: U2.2 (I2), U3.3 (Q4), U11.5 (A1)
VQ5: U2.1 (I1/CLK), U3.2 (Q5), U10.11 (C), U11.3 (A2)
VQ6: U2.3 (I3), U3.4 (Q6), U11.14 (A3)
VQ8: U2.5 (I5), U3.12 (Q8), U10.12 (D), U10.13 (~R), U31.1
VRESET: CX2.1, U2.19 (IO1), U3.11 (MR)
~CSYNC: D3.1 (K), D4.2 (A), R11.2, U2.14 (IO6)
~HSYNC: D4.1 (K), JMP10.1, JMP10.2, P1.5, P6.8, U1.8
~RD: U24.13; also elsewhere on the board
~VIDCLK: U19.1 (S), U20.1 (S), U21.1 (S), U22.1 (S), U24.4, U24.11, U41.11 (Cp)
~VSYNC: D3.2 (A), P1.4, P6.10, U1.6
~VWR: U18.8, U30.27 (~WE), U42.1 (OEa), U42.19 (OEb)
~WR: U14.13; also elsewhere on the board

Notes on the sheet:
HRESET = HQ9 * HQ8 HSYNC = HQ9 * /HQ8 * /HQ7 * HQ6 VRESET = VQ8 * VQ6 VSYNC = VQ8 * /VQ5 * VQ4 * VQ3
Composite

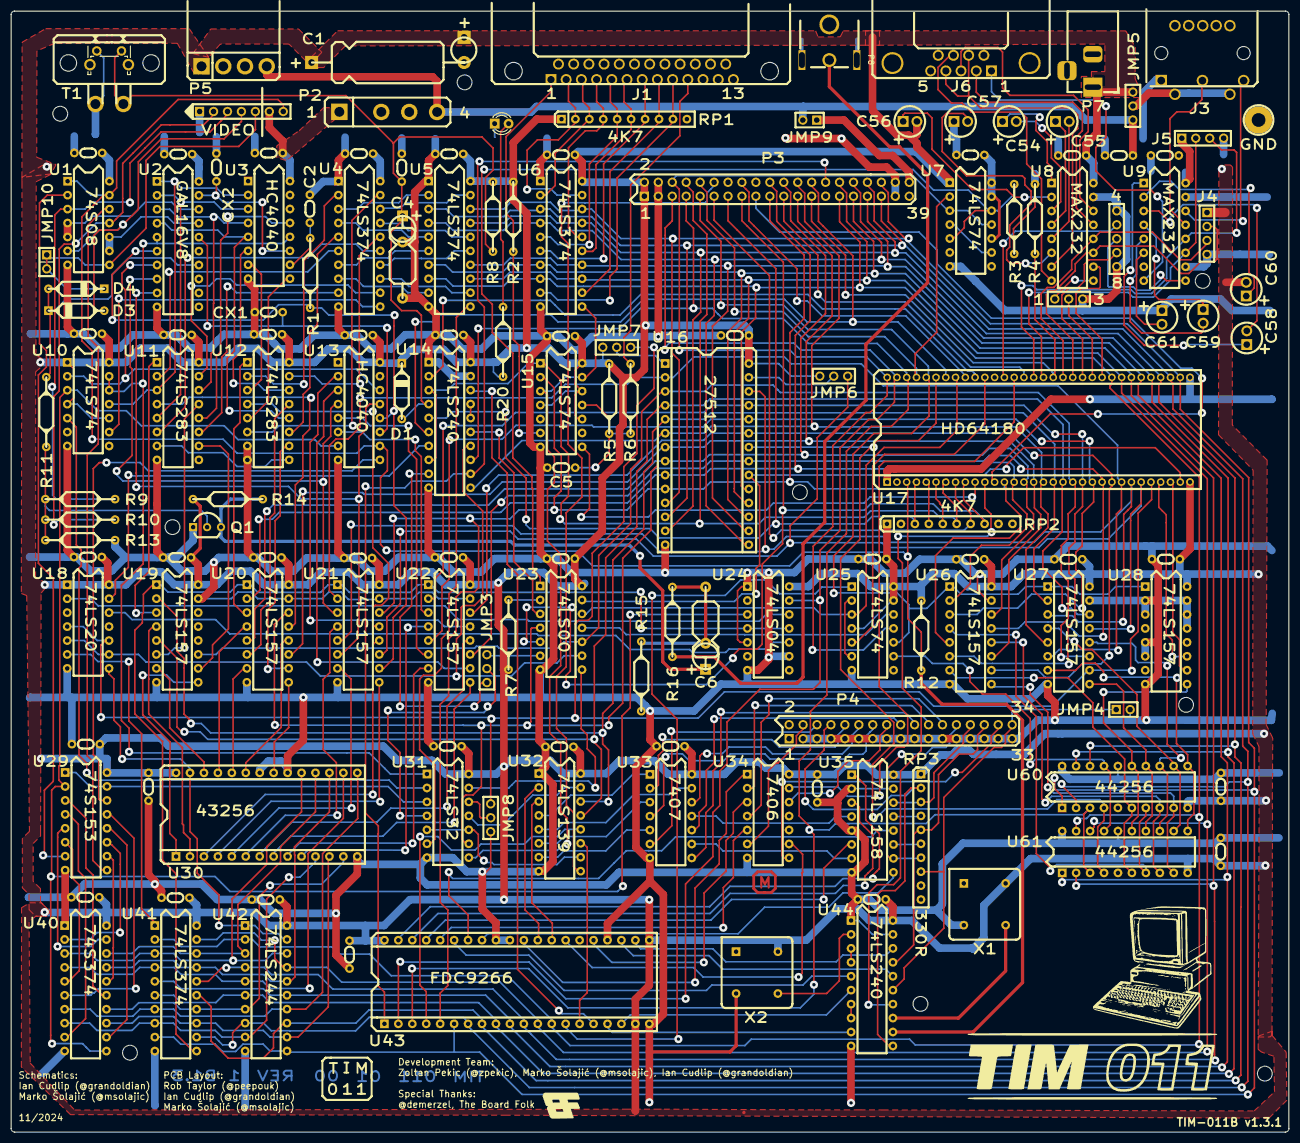
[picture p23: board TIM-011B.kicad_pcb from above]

Board: 2 copper layers, 232.8 x 204.2 mm, 162 parts (0 on the bottom side), 277 nets.

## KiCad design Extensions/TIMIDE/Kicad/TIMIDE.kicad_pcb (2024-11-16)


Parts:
C401, C402, C403, C404, C405: 100nF; Ceramic Cap 5.00mm
C406: 100uF; Electrolytic Capacitor Axial or Radial Alt
H401: MountingHole; MountingHole_M2.5
P1, P2: EXPAND; PinHeader_2x20 2.54mm

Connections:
+5V: C401.1, C402.1, C403.1, C404.1, C405.1, C406.1, P1.1, P1.2, P2.1, P2.2; also elsewhere on the board
/CF IDE Interface/A0: P1.19, P2.19; also elsewhere on the board
/CF IDE Interface/A1: P1.20, P2.20; also elsewhere on the board
/CF IDE Interface/A2: P1.22, P2.22; also elsewhere on the board
/CF IDE Interface/A3: P1.23, P2.23; also elsewhere on the board
/CF IDE Interface/A4: P1.24, P2.24; also elsewhere on the board
/CF IDE Interface/D0: P1.36, P2.36; also elsewhere on the board
/CF IDE Interface/D1: P1.35, P2.35; also elsewhere on the board
/CF IDE Interface/D2: P1.34, P2.34; also elsewhere on the board
/CF IDE Interface/D3: P1.32, P2.32; also elsewhere on the board
/CF IDE Interface/D4: P1.33, P2.33; also elsewhere on the board
/CF IDE Interface/D5: P1.31, P2.31; also elsewhere on the board
/CF IDE Interface/D6: P1.30, P2.30; also elsewhere on the board
/CF IDE Interface/D7: P1.29, P2.29; also elsewhere on the board
E: P1.9, P2.9
EXPSEL_2: P1.14, P2.14
EXPSEL_3: P1.18, P2.18
EXPSEL_O: P1.12, P2.12; also elsewhere on the board
FI: P1.6, P2.6; also elsewhere on the board
GND: C401.2, C402.2, C403.2, C404.2, C405.2, C406.2, P1.3, P1.4, P1.37, P1.38, P2.3, P2.4, P2.37, P2.38; also elsewhere on the board
PIN_27: P1.27, P2.27
PIN_39: P1.39, P2.39
PIN_40: P1.40, P2.40
RESET: P1.28, P2.28
ST: P1.17, P2.17
~DREQ0: P1.25, P2.25
~HALT: P1.16, P2.16
~INT0: P1.15, P2.15
~IOE: P1.26, P2.26
~LIR: P1.10, P2.10; also elsewhere on the board
~NMI: P1.11, P2.11
~RD: P1.5, P2.5; also elsewhere on the board
~RESET: P1.8, P2.8; also elsewhere on the board
~TEND0: P1.21, P2.21
~WAIT: P1.13, P2.13
~WR: P1.7, P2.7; also elsewhere on the board


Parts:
D401: ACT; TIM_LED_D3.0mm
D402: POWER; TIM_LED_D3.0mm
J401: IDE/CF; PinHeader_2x20 2.54mm
J402: ADDR SEL; TIM_Address_2x04
R401, R402, R403: 4K7; Resistor 12.7mm
R404, R405: 1K; Resistor 12.7mm
U401: 74LS74; DIP-14_W7.62mm
U402: 74LS32; DIP-14_W7.62mm
U403: 74LS138; DIP-16_W7.62mm
U404: 74LS245; DIP-20_W7.62mm

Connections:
+5V: D401.2 (A), D402.2 (A), J401.20, R401.1, R402.1, R403.1, U401.4 (~S), U401.10 (~S), U401.12 (D), U401.14 (VCC), U402.14 (VCC), U403.16 (VCC), U404.20 (VCC); also elsewhere on the board
/CF IDE Interface/A0: J401.35; also elsewhere on the board
/CF IDE Interface/A1: J401.33; also elsewhere on the board
/CF IDE Interface/A2: J401.36; also elsewhere on the board
/CF IDE Interface/A3: U403.1 (A0); also elsewhere on the board
/CF IDE Interface/A4: U403.2 (A1); also elsewhere on the board
/CF IDE Interface/BD0: J401.17, U404.18 (B0)
/CF IDE Interface/BD1: J401.15, U404.17 (B1)
/CF IDE Interface/BD2: J401.13, U404.16 (B2)
/CF IDE Interface/BD3: J401.11, U404.15 (B3)
/CF IDE Interface/BD4: J401.9, U404.14 (B4)
/CF IDE Interface/BD5: J401.7, U404.13 (B5)
/CF IDE Interface/BD6: J401.5, U404.12 (B6)
/CF IDE Interface/BD7: J401.3, U404.11 (B7)
/CF IDE Interface/D0: U404.2 (A0); also elsewhere on the board
/CF IDE Interface/D1: U404.3 (A1); also elsewhere on the board
/CF IDE Interface/D2: U404.4 (A2); also elsewhere on the board
/CF IDE Interface/D3: U404.5 (A3); also elsewhere on the board
/CF IDE Interface/D4: U404.6 (A4); also elsewhere on the board
/CF IDE Interface/D5: U404.7 (A5); also elsewhere on the board
/CF IDE Interface/D6: U404.8 (A6); also elsewhere on the board
/CF IDE Interface/D7: U404.9 (A7); also elsewhere on the board
EXPSEL_O: U401.13 (~R), U404.19 (CE); also elsewhere on the board
FI: U401.3 (C), U401.11 (C), U402.12; also elsewhere on the board
GND: J401.2, J401.19, J401.22, J401.24, J401.26, J401.30, J401.40, R405.2, U401.7 (GND), U402.5, U402.7 (GND), U403.3 (A2), U403.5 (E2), U403.8 (GND), U404.10 (GND); also elsewhere on the board
unnamed: D401.1 (K), R404.1
unnamed: D402.1 (K), R405.1
unnamed: J401.23, U402.6
unnamed: J401.25, U402.8
unnamed: J401.29, R403.2
unnamed: J401.34, R401.2
unnamed: J401.38, R402.2
unnamed: J401.39, R404.2
unnamed: J402.1, U403.15 (O0)
unnamed: J402.3, U403.14 (O1)
unnamed: J402.5, U403.13 (O2)
unnamed: J402.7, U403.12 (O3)
unnamed: U401.5 (Q), U402.10
unnamed: U401.1 (~R), U402.11
unnamed: U401.9 (Q), U403.4 (E1)
unnamed: U402.3, U402.4
~IDE_CS: J401.37, J402.2, J402.4, J402.6, J402.8, U402.1
~LIR: U403.6 (E3); also elsewhere on the board
~RD: U401.2 (D), U402.9, U402.13, U404.1 (A->B); also elsewhere on the board
~RESET: J401.1; also elsewhere on the board
~WR: U402.2; also elsewhere on the board

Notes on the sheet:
E0 E8 F0 F8

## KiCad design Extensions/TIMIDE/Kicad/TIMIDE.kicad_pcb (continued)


Board: 2 copper layers, 75.3 x 72.2 mm, 22 parts (0 on the bottom side), 61 nets.

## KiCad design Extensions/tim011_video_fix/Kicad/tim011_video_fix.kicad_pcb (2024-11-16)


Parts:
C1: 1n; Ceramic Cap 5.00mm
C2: 4n7; Ceramic Cap 5.00mm
C3, C4: 10n; Ceramic Cap 5.00mm
C5, C6, C7: 100n; Ceramic Cap 5.00mm
C8: 470uF 25v; Electrolytic Capacitor Axial or Radial Alt
C9: 2n2; Ceramic Cap 5.00mm
H1, H2, H3: MountingHole; MountingHole_M2.5
J3: Comp; RCA2
J4: 9 pin; TIM_DSUB-9
P1: Input; PinHeader_1x06 2.54mm
P2: RGBtoHDMI; PinHeader_2x6_2.54mm
P3: Power; 3.96mm Header 2-Pin
Q1: BC557; TO-92_Inline_Wide
R1: 3K3; Resistor 12.7mm
R2: 2k2; Resistor 12.7mm
R3, R9: 10K; Resistor 12.7mm
R4: 47K; Resistor 12.7mm
R5: 1K; Resistor 12.7mm
R6: 5K1; Resistor 12.7mm
R7: 1K5; Resistor 12.7mm
R8: 2K2; Resistor 12.7mm
R10: 220R; Resistor 12.7mm
R11: 68R; Resistor 12.7mm
RV1: 50K; TIM Multi Pot
RV2: 100K; TIM Multi Pot
U1, U2: 74LS123; DIP-16_W7.62mm
U3: 74LS08; DIP-14_W7.62mm

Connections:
+5V: C5.1, C6.1, C7.1, P1.6, P2.12, P3.1, R2.1, R4.1, R10.1, RV1.1, RV1.2, RV2.1, RV2.2, U1.3 (Clr), U1.11 (Clr), U1.16 (VCC), U2.3 (Clr), U2.11 (Clr), U2.16 (VCC), U3.14 (VCC)
CSYNC: R6.2, U3.3
GND: C1.2, C2.2, C3.2, C4.2, C5.2, C6.2, C7.2, C9.2, J3.2 (Ext), J4.0 (PAD), J4.1, J4.2, P1.1, P2.3, P3.2, Q1.1 (C), R5.2, R9.2, U1.1 (A), U1.6 (Cext), U1.8 (GND), U1.9 (A), U1.14 (Cext), U2.1 (A), U2.6 (Cext), U2.8 (GND), U2.9 (A), U2.14 (Cext), U3.4, U3.5, U3.7 (GND)
HSYNC_IN: P1.5, U1.2 (B)
HSYNC_OUT: C9.1, J4.8, P2.8, U1.12 (~Q), U3.1
unnamed: C8.2, R9.1, R11.1
unnamed: J3.1 (In), R11.2
unnamed: Q1.2 (B), R5.1, R6.1, R7.1, R8.1
unnamed: C8.1, Q1.3 (E), R10.2
unnamed: R1.1, RV1.3
unnamed: R3.1, RV2.3
unnamed: C1.1, R1.2, U1.15 (RCext)
unnamed: U1.4 (~Q), U1.10 (B)
unnamed: C2.1, R2.2, U1.7 (RCext)
unnamed: C3.1, R3.2, U2.15 (RCext)
unnamed: U2.4 (~Q), U2.10 (B)
unnamed: C4.1, R4.2, U2.7 (RCext)
VID1: J4.3, J4.4, J4.5, P1.2, P2.9, U3.9, U3.10
VID1B: R7.2, U3.8
VID2: J4.6, P1.3, P2.4, U3.12, U3.13
VID2B: R8.2, U3.11
VSYNC_IN: P1.4, U2.2 (B)
VSYNC_OUT: J4.9, P2.10, U2.12 (~Q), U3.2

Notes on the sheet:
HSYNC_OUT negative pulse length cca. 3.5 uS VSYNC_OUT negative pulse length cca. 450 uS


Board: 2 copper layers, 84.9 x 57.4 mm, 34 parts (0 on the bottom side), 23 nets.

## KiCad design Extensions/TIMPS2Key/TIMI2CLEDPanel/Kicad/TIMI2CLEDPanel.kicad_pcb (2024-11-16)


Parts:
C1: 47nF; C_Disc_D4.3mm_W1.9mm_P5.00mm
D1: POWER; LED_D3.0mm
D2: LINE; LED_D3.0mm
D3: LOCAL; LED_D3.0mm
D4: CAPS; LED_D3.0mm
D5: LOCK; LED_D3.0mm
D6: L1; LED_D3.0mm
D7: L2; LED_D3.0mm
D8: L3; LED_D3.0mm
D9: L4; LED_D3.0mm
G1: Board Folk Logo; BF8
H2, H3, H4, H5: MountingHole; MountingHole_2.1mm
J1, J4: I2C; PinHeader_1x04_P2.54mm_Vertical
R1: 1K; R_Axial_DIN0204_L3.6mm_D1.6mm_P7.62mm_Horizontal
R2, R3, R4, R5, R6, R7, R8, R9: 470R; R_Axial_DIN0204_L3.6mm_D1.6mm_P7.62mm_Horizontal
R10: 10K; R_Axial_DIN0204_L3.6mm_D1.6mm_P7.62mm_Horizontal
U1: PCF8574; DIP-16_W7.62mm

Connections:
+5V: C1.2, J1.1, J4.1, R1.1, U1.16 (VDD)
/LED0: R2.1, U1.12 (P7)
/LED1: R3.1, U1.11 (P6)
/LED2: R4.1, U1.10 (P5)
/LED3: R5.1, U1.9 (P4)
/LED4: R6.1, U1.7 (P3)
/LED5: R7.1, U1.6 (P2)
/LED6: R8.1, U1.5 (P1)
/LED7: R9.1, U1.4 (P0)
GND: C1.1, D1.1 (K), D2.1 (K), D3.1 (K), D4.1 (K), D5.1 (K), D6.1 (K), D7.1 (K), D8.1 (K), D9.1 (K), J1.2, J4.2, R10.1, U1.8 (VSS)
N_SCL: J1.4, J4.4, U1.14 (SCL)
N_SDA: J1.3, J4.3, U1.15 (SDA)
unnamed: D1.2 (A), R1.2
unnamed: D2.2 (A), R2.2
unnamed: D3.2 (A), R3.2
unnamed: D4.2 (A), R4.2
unnamed: D5.2 (A), R5.2
unnamed: D6.2 (A), R6.2
unnamed: D7.2 (A), R7.2
unnamed: D8.2 (A), R8.2
unnamed: D9.2 (A), R9.2
unnamed: R10.2, U1.1 (A0), U1.2 (A1), U1.3 (A2)



Board: 2 copper layers, 90.0 x 18.0 mm, 28 parts (14 on the bottom side), 22 nets.

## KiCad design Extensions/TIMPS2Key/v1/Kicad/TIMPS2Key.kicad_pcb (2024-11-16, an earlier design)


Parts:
BZ1: Buzzer; MagneticBuzzer_ProSignal_ABT-410-RC
C1: 100uF; CP_Radial_D5.0mm_P2.00mm
C3: 47uF; CP_Radial_D5.0mm_P2.00mm
C4: 220nF; C_Disc_D4.3mm_W1.9mm_P5.00mm
C5, C6, C7, C8: 1uF; CP_Radial_D4.0mm_P2.00mm
D1: POWER; LED_D3.0mm
G1: Board Folk Logo; BF8
H2, H3, H4, H5: MountingHole; MountingHole_2.1mm
J1: DIN Serial; DINSerial
J2: PS/2; Connector_Mini-DIN_Female_6Pin_2rows
J3: 5V IN; PinHeader_1x02_P2.54mm_Vertical
J4: I2C; PinHeader_1x04_P2.54mm_Vertical
Q1: BC550; TO-92_Inline_Wide
R1: 1K; R_Axial_DIN0204_L3.6mm_D1.6mm_P7.62mm_Horizontal
R2: 10R; R_Axial_DIN0204_L3.6mm_D1.6mm_P7.62mm_Horizontal
R3: 150R; R_Axial_DIN0204_L3.6mm_D1.6mm_P7.62mm_Horizontal
R4, R5: 10K; R_Axial_DIN0204_L3.6mm_D1.6mm_P7.62mm_Horizontal
U1: NANO Socket; Arduino_Nano_WithMountingHoles
U2: MAX232; DIP-16_W7.62mm
U3: LM7805_TO220; TO-220-3_Vertical

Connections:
+5V: BZ1.1 (+), C1.1, C4.2, C5.2, J2.4, J3.1, J4.1, R1.1, R4.1, R5.1, U1.27, U2.16 (VCC), U3.3 (VO)
+12V: C3.1, J1.4, J1.5, U3.1 (VI)
GND: C1.2, C3.2, C4.1, C6.1, D1.1 (K), J1.1, J1.G, J2.3, J2.7, J3.2, J4.2, R2.1, U1.4, U1.29, U2.8 (R2IN), U2.10 (T2IN), U2.15 (GND), U3.2 (GND)
N_RX: U1.2, U2.12 (R1OUT)
N_SCL: J4.4, R4.2, U1.24
N_SDA: J4.3, R5.2, U1.23
N_TX: U1.1, U2.11 (T1IN)
unnamed: BZ1.2 (-), Q1.1 (C)
unnamed: D1.2 (A), R1.2
unnamed: Q1.2 (B), R3.1
unnamed: Q1.3 (E), R2.2
unnamed: C7.1, U2.1 (C1+)
unnamed: C7.2, U2.3 (C1-)
unnamed: C8.1, U2.4 (C2+)
unnamed: C8.2, U2.5 (C2-)
unnamed: C5.1, U2.2 (VS+)
unnamed: C6.2, U2.6 (VS-)
PS2-CLK: J2.5, U1.6
PS2-DATA: J2.1, U1.15
SOUND: R3.2, U1.19
S_RX: J1.3, U2.13 (R1IN)
S_TX: J1.2, U2.14 (T1OUT)


Board: 2 copper layers, 94.8 x 32.2 mm, 27 parts (0 on the bottom side), 22 nets.

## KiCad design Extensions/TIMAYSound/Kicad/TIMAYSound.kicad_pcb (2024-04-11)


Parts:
C201, C202: 30pF; Ceramic Cap 5.00mm
C203, C204, C205: 100nF; Ceramic Cap 5.00mm
J201: STEREO JACK; STEREO
J202: JOYSTICK
J203: IO; PinHeader_1x08_P2.54mm_Vertical; not fitted
NR201: 10K; R_Array_SIP9
P1, P2: EXPAND; PinHeader_2x20 2.54mm
R201, R202, R203: 1K; Resistor 12.7mm; LCSC C482939
R205, R210: 10K; Resistor 12.7mm; LCSC C84376
R207, R209: 22K; Resistor 12.7mm; LCSC C114565
R211: 2M; Resistor 12.7mm; LCSC C84376
R212: 1K; Resistor 12.7mm; LCSC C84376
U201: AY-3-8912; DIP-28_W15.24mm_Socket
U202: AY-3-8910; DIP-40_W15.24mm_Socket
U203: 74HCU04; DIP-14_W7.62mm
U204: 74LS08; DIP-14_W7.62mm
Y201: 1.843MHz; Crystal_Horizontal

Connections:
+5V: C203.1, C204.1, C205.1, J202.7, NR201.1 (common), P1.1, P1.2, P2.1, P2.2, U201.3 (VCC), U201.17 (A8), U201.19 (BC2), U202.25 (A8), U202.28 (BC2), U202.40 (VCC), U203.14 (VCC), U204.14 (VCC)
/A0: P1.19, P2.19
/A1: P1.20, P2.20
/A2: P1.22, P2.22
/A3: P1.23, P2.23, U204.4
/A4: P1.24, P2.24, U204.1
/AYIO0: J202.4, J203.1, NR201.9 (R8), U201.14 (IOA0), U202.21 (IOA0)
/AYIO1: J202.3, J203.2, NR201.8 (R7), U201.13 (IOA1), U202.20 (IOA1)
/AYIO2: J202.2, J203.3, NR201.7 (R6), U201.12 (IOA2), U202.19 (IOA2)
/AYIO3: J202.1, J203.4, NR201.6 (R5), U201.11 (IOA3), U202.18 (IOA3)
/AYIO4: J202.6, J203.5, NR201.5 (R4), U201.10 (IOA4), U202.17 (IOA4)
/AYIO5: J202.5, J203.6, NR201.4 (R3), U201.9 (IOA5), U202.16 (IOA5)
/AYIO6: J203.7, NR201.3 (R2), U201.8 (IOA6), U202.15 (IOA6)
/AYIO7: J202.9, J203.8, NR201.2 (R1), U201.7 (IOA7), U202.14 (IOA7)
/D0: P1.36, P2.36, U201.28 (DA0), U202.37 (DA0)
/D1: P1.35, P2.35, U201.27 (DA1), U202.36 (DA1)
/D2: P1.34, P2.34, U201.26 (DA2), U202.35 (DA2)
/D3: P1.32, P2.32, U201.25 (DA3), U202.34 (DA3)
/D4: P1.33, P2.33, U201.24 (DA4), U202.33 (DA4)
/D5: P1.31, P2.31, U201.23 (DA5), U202.32 (DA5)
/D6: P1.30, P2.30, U201.22 (DA6), U202.31 (DA6)
/D7: P1.29, P2.29, U201.21 (DA7), U202.30 (DA7)
AYA: R202.2, R207.2, R209.2, U201.4 (A), U202.4 (A)
AYB: R203.2, R210.2, U201.5 (B), U202.3 (B)
AYBC1: U201.20 (BC1), U202.29 (BC1), U204.6
AYBDIR: U201.18 (BDIR), U202.27 (BDIR), U204.11
AYC: R201.2, R205.2, U201.1 (C), U202.38 (C)
AYCLK: U201.15 (CLOCK), U202.22 (CLOCK), U203.4
E: P1.9, P2.9
EXPSEL_O: P1.12, P2.12, U203.1
FI: P1.6, P2.6
GND: C201.1, C202.1, C203.2, C204.2, C205.2, J201.1, J202.0 (PAD), J202.8, P1.3, P1.4, P1.37, P1.38, P2.3, P2.4, P2.37, P2.38, R201.1, R202.1, R203.1, U201.6 (GND), U202.1 (GND), U202.24 (~A9), U203.5, U203.7 (GND), U203.13, U204.7 (GND), U204.9, U204.10
unnamed: C201.2, R211.2, U203.9, Y201.1
unnamed: C202.2, R212.2, Y201.2
unnamed: J201.3 (Ground), R209.1, R210.1
unnamed: J201.2, R205.1, R207.1
unnamed: R211.1, R212.1, U203.8, U203.11
unnamed: U203.2, U204.2
unnamed: U203.3, U203.10
unnamed: U204.3, U204.5, U204.12
RESET: P1.28, P2.28
ST: P1.17, P2.17
~DREQ0: P1.25, P2.25
~HALT: P1.16, P2.16
~INT0: P1.15, P2.15
~IOE: P1.26, P2.26
~LIR: P1.10, P2.10
~NMI: P1.11, P2.11
~RD: P1.5, P2.5, U204.13
~RESET: P1.8, P2.8, U201.16 (~RESET), U202.23 (~RESET)
~TEND0: P1.21, P2.21
~WAIT: P1.13, P2.13
~WR: P1.7, P2.7

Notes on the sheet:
AUDIO OUT


Board: 2 copper layers, 74.1 x 69.3 mm, 24 parts (0 on the bottom side), 53 nets.

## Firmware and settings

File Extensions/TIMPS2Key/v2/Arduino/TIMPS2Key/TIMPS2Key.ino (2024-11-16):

// TIMPS2Key v2
// PS/2 Keyboard interface for the TIM-011
// v2 including Sound and LEDs via I2C
// @grandoldian 05/2024
// v2.0 25/05/2024

#include <Wire.h>
#include <PS2KeyAdvanced.h>
#include "TIMPS2Key.h"

PS2KeyAdvanced keyboard;
TIMkeyboard tkey;

byte cmdState=0;
// cmdState = 0 - no command
//            1 - command being received
//            2 - command active

byte ledState=0xcf;  // bits of led

void setup() {
  char outChar=0xff;

  keyboard.begin(DATA_PIN, IRQ_PIN);
  keyboard.setNoRepeat(0);
  keyboard.setNoBreak(0);
  keyboard.setLock(PS2_LOCK_CAPS + PS2_LOCK_NUM);
  Wire.begin();
  tkey.begin();

  if (debug) {
    Serial.begin (9600,SERIAL_8N1);
  } else {
    Serial.begin (9600,SERIAL_8E1);
  }

  // Initialise LED
  tkey.setSpecial(0x25);    // What's the default?
  tkey.setLed(ledState);

  // Send 0xff denoting power up
  Serial.print(outChar);
  Serial.flush();
}

void loop() {

      byte readByte=0;

      if ( keyboard.available() ) {
        tkey.Input(keyboard.read());
      }

    if (Serial.available() > 0) {
      readByte=Serial.read();
      if (debug) {
        Serial.print("Read byte:");
        Serial.println(readByte,HEX);
      }
      if ((readByte==0x40) && (cmdState==2)) {
        tkey.stopCmd();
        cmdState=0;
      } else {
        // Reset, start again
        if ((readByte==0x00) && (cmdState==2)) {
          tkey.stopCmd();
          cmdState=0;
        }
        // Reset End
        if ((readByte==0x00) && (cmdState==0)) {
          cmdState++; 
        } else {
          if (cmdState==1) {
            // Process Command

            // Beep
            if ((readByte>=0x40) && (readByte<=0x7f)) {
              cmdState++;
              tkey.beep(readByte);
              if ((readByte==0x40) || (readByte==0x7f)) {
                // that's all you get
                cmdState=0;
              }
            }

            // LED 
            if (readByte<=0x3f) {
              cmdState=0;
              ledState=(((readByte & 0x01)<<4)+   // kb lock
                        ((readByte & 0x20)>>5)+   // l4
                        ((readByte & 0x10)>>3)+   // l3
                        ((readByte & 0x08)>>1)+   // l2
                        ((readByte & 0x04)<<1));  // l1
              if (readByte & 0x02) {
                ledState+=0x80;                   // line
              } else {
                ledState+=0x40;                   // local
              }
              tkey.setLed(ledState);
            }

            // Special bit 7

            if ((cmdState==1) && (readByte & 0x80)) {
              cmdState=0;
              tkey.setSpecial(readByte);
            }

            // Unknown command, leave the state
            if (cmdState==1) {
              cmdState=0;
            }

          }
        }
      }
    } 
}

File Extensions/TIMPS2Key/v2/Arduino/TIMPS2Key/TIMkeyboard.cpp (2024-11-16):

// TIMkeyboard.cpp
// @grandoldian 05/2024
// v2.0 25/05/2024

#include <Wire.h>
#include "TIMPS2key.h"
#include "keymap.h"

int lctrl_pressed=0;
int rctrl_pressed=0;
int capslock=1;
byte ledTrack=0;
byte keylock=0;
byte autorepeat=0;  // 0 off, 1 slow, 2 fast
byte linelocal=0;   // 0 local, 1 line
byte keybeep=0;
byte keyclick=0;
byte repeatdelay=0; // 0 short, 1 long

void TIMkeyboard::setLed(byte led) {
  byte outLed=0;

    if (debug) {
      Serial.println("LED");
      Serial.println(led,HEX);
      Serial.println("");
    }

    ledTrack=led;

    outLed=(led&0x3f)+(capslock<<5)+(1<<(!linelocal+6));

    // invert appropriate bits
    outLed=outLed^0xcf;

    keylock=(outLed & 0x10)!=0;

    if ((keylock) && (debug)) {
      Serial.println("Keyboard Locked");
    } 

    if ((!keylock) && (debug)) {
      Serial.println("Keyboard Unlocked");
    } 

    Wire.beginTransmission(LED_PORT);
    Wire.write(outLed);
    Wire.endTransmission();
}

void TIMkeyboard::setSpecial(byte special)
{

  if ((special & 0x40)>0) {
  autorepeat=1;
  } else {
    if ((special & 0x20)>0) {
      autorepeat=2;
    } else {
      autorepeat=0;
    }
  }

  keybeep=((special & 0x08)>0);
  keyclick=((special & 0x04)>0);
  repeatdelay=((special & 0x02)==0);
  linelocal=((special & 0x01)>0);

  if (debug) {
    Serial.print("Autorepeat: ");
    Serial.println(autorepeat,DEC);
    Serial.print("Key Beep: ");
    Serial.println(keybeep,DEC);
    Serial.print("Key Click: ");
    Serial.println(keyclick,DEC);
    Serial.print("Repeat Delay: ");
    Serial.println(repeatdelay,DEC);
    Serial.print("Line Local: ");
    Serial.println(linelocal,DEC);
  }
}

void TIMkeyboard::keyBeep()
{
  tone(BUZZER_PIN, 770);
  delay(5);
  noTone(BUZZER_PIN);
}

void TIMkeyboard::keyClick()
{
  tone(BUZZER_PIN, 1256);
  delayMicroseconds(500);
  noTone(BUZZER_PIN);
}

void TIMkeyboard::beep(byte cmd) {
   if (debug) {
    Serial.println("Beep");
    Serial.println(cmd,HEX);
    Serial.println("");
   }
   switch (cmd) {
    case 0x40:
     tone(BUZZER_PIN, 770);
     delay(1000);
     noTone(BUZZER_PIN);
     break;
    case 0x41:
     break;
    case 0x42:
    case 0x62:
     tone(BUZZER_PIN, 165);
     break;
    case 0x43:
    case 0x63:
     tone(BUZZER_PIN, 174);
     break;
    case 0x44:
    case 0x64:
     tone(BUZZER_PIN, 185);
     break;
    case 0x45:
    case 0x65:
     tone(BUZZER_PIN, 196);
     break;
    case 0x46:
    case 0x66:
     tone(BUZZER_PIN, 207);
     break;
    case 0x47:
    case 0x67:
     tone(BUZZER_PIN, 220);
     break;
    case 0x48:
    case 0x68:
     tone(BUZZER_PIN, 233);
     break;
    case 0x49:
    case 0x69:
     tone(BUZZER_PIN, 247);
     break;
    case 0x4a:
    case 0x6a:
     tone(BUZZER_PIN, 261);
     break;
    case 0x4b:
    case 0x6b:
     tone(BUZZER_PIN, 277);
     break;
    case 0x4c:
    case 0x6c:
     tone(BUZZER_PIN, 294);
     break;
    case 0x4d:
    case 0x6d:
     tone(BUZZER_PIN, 310);
     break;
    case 0x4e:
    case 0x6e:
     tone(BUZZER_PIN, 330);
     break;
    case 0x4f:
    case 0x6f:
     tone(BUZZER_PIN, 349);
     break;
    case 0x50:
    case 0x70:
     tone(BUZZER_PIN, 370);
     break;
    case 0x51:
    case 0x71:
     tone(BUZZER_PIN, 390);
     break;
    case 0x52:
    case 0x72:
     tone(BUZZER_PIN, 415);
     break;
    case 0x53:
    case 0x73:
     tone(BUZZER_PIN, 440);
     break;
    case 0x54:
    case 0x74:
     tone(BUZZER_PIN, 466);
     break;
    case 0x55:
    case 0x75:
     tone(BUZZER_PIN, 494);
     break;
    case 0x56:
    case 0x76:
     tone(BUZZER_PIN, 523);
     break;
    case 0x57:
    case 0x77:
     tone(BUZZER_PIN, 554);
     break;
    case 0x58:
    case 0x78:
     tone(BUZZER_PIN, 586);
     break;
    case 0x59:
    case 0x79:
     tone(BUZZER_PIN, 622);
     break;
    case 0x5a:
    case 0x7a:
     tone(BUZZER_PIN, 660);
     break;
    case 0x5b:
    case 0x7b:
     tone(BUZZER_PIN, 698);
     break;
    case 0x5c:
    case 0x7c:
     tone(BUZZER_PIN, 740);
     break;
    case 0x5d:
    case 0x7d:
     tone(BUZZER_PIN, 784);
     break;
    case 0x5e:
    case 0x7e:
     tone(BUZZER_PIN, 830);
     break;
    case 0x5f:
     tone(BUZZER_PIN, 515);
     break;
    case 0x7f:
     tone(BUZZER_PIN, 770);
     delay(100);
     noTone(BUZZER_PIN);
     break;
   }
}

void TIMkeyboard::stopCmd() {
   if (debug) {
    Serial.println("Stop Command");
   }
   noTone(BUZZER_PIN);
}
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

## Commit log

2024-03-26 Initial Version 1 BOM
2024-04-04 Fix J4, J5.
    [tim_keyboard.kicad_sch]
2024-04-05 Updates
    Moved C6 and C7 to stop chances of shorting with crystals. U15 silkscreen designator moved.
2024-04-06 U18 correction, ROM A13 ground, DB25 mouting hole fix, remove H9, Credits Update
    [TIM-011B.kicad_sch, tim_cpu.kicad_sch]
2024-04-08 JMP4 Floppy Ready/Disk Change Mod
    [tim_floppy.kicad_sch]
2024-04-09 Upload TIMPS2Key v0
    [TIMPS2Key-B_Cu.gbr, TIMPS2Key-B_Mask.gbr, TIMPS2Key-B_Paste.gbr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]
2024-04-11 Added TIMAYSound
    [TIMAYSound-B_Cu.gbr, TIMAYSound-B_Mask.gbr, TIMAYSound-B_Paste.gbr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]
2024-04-12 v1.1 Upload
    [TIM-011B-B_Cu.gbr, TIM-011B-B_Mask.gbr, TIM-011B-B_Paste.gbr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]
2024-11-16 v1.3 Initial Notes
    [TIM-011B-B_Cu.gbr, TIM-011B-B_Mask.gbr, TIM-011B-B_Paste.gbr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]
2024-11-16 v1.3 BOM
2024-11-16 v1.3 Import
    [TIM-011B-B_Cu.gbr, TIM-011B-B_Mask.gbr, TIM-011B-B_Paste.gbr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]
2024-11-16 PS/2 Keyboard revisions v1 (Nano) and v2 (328) and i2c board.
    [TIMI2CLEDPanel-B_Cu.gbr, TIMI2CLEDPanel-B_Mask.gbr, TIMI2CLEDPanel-B_Paste.gbr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]
2024-11-16 Add tim011_video_fix
    [tim011_video_fix-B_Cu.gbr, tim011_video_fix-B_Mask.gbr, tim011_video_fix-B_Paste.gbr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]
2024-12-14 v1.3.1 Silkscreen Update
    [TIM-011B-B_Cu.gbr, TIM-011B-B_Mask.gbr, TIM-011B-B_Paste.gbr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]
